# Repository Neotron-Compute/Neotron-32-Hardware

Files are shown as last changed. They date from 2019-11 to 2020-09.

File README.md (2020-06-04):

# Neotron 32

## A simple 32K ARM-powered home computer.

The Neotron 32 brings the classic 1980s home-computer design up-to-date. Our tech is based on the tried and true single board ARM computer model offering a hacker friendly platform for your retro project. It aims to bring the retro computing feel, with DOS and BASIC like environments and semi-modern interfaces, like SD cards and SVGA. And all the system software is Open Source and written in the Rust Programming Language, and all the hardware is Open Source too.

With an ARM Cortex-M4 based MCU the Neotron-32 gets you right back into the hardware. With only 32 KiB of RAM, the challenge is to squeeze the maximum out of the minimum amount of resources. We've got 48x36 text mode, 384x288 bitmap mode, 3-channel audio synthesiser, joystick support and FAT filesystem support ... but there's still room for you to squeeze some more out the system.

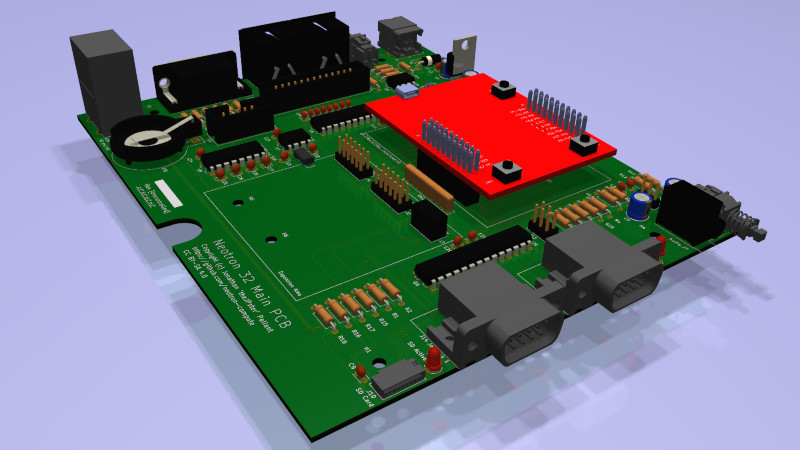
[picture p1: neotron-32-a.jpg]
Right Hand View


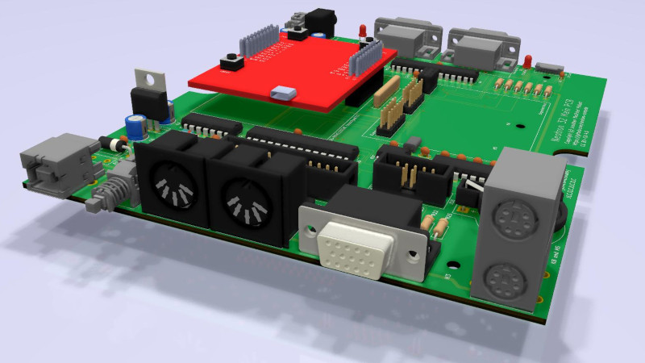
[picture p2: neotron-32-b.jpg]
Left Hand View


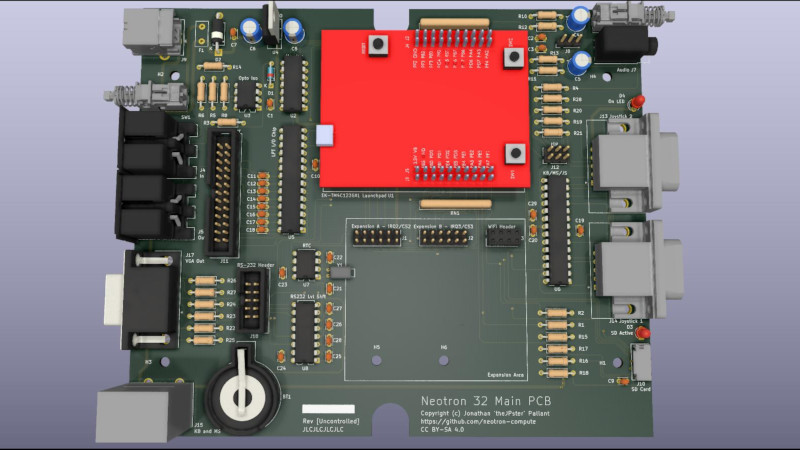
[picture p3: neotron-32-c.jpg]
Top View


## Hardware

  - **CPU:** Texas Instruments Tiva-C TM4C123
  - **Processor Core**: 80 MHz ARM Cortex-M4 (approximately 95% CPU taken drawing the screen, leaving a ~ 4 MHz ARM)
  - **RAM:** 32 KiB on-chip SRAM
  - **ROM:** 256 KiB on-chip Flash
  - **GPU:** No GPU - CPU generates 8 colour 400x300 video
  - **GPU RAM:** Shared with main SRAM
  - **Video Output:** VGA (fixed at 800x600 60 Hz)
  - **Storage:** Micro SD Card slot, supports FAT16/FAT32 and MS-DOS partition tables
  - **USB:** 1x USB 2.0 Full-speed OTG micro-AB port (internal - support TBD)
  - **Audio:** 3.5mm Line Out with Mono/Stereo jumper
  - **Keyboard/Mouse:** 2x PS/2 Ports (2x 6-pin mini-DIN)
  - **MIDI**: MIDI In and MIDI Out (2x 5-pin 180-degree DIN)
  - **Serial**: RS-232 on 10-pin 2.54mm header suitable for DE-9 plug on IDC ribbon
  - **Parallel**: 3.3v PC-style Parallel Port on 26-pin 2.54mm header suitable for DB-25 plug on IDC ribbon. Also functions as 3.3v GPIO with 12 outputs and 4 inputs.
  - **Joystick**: 2x 9-pin game ports (supports Atari-compatible two-button joysticks, or SEGA MegaDrive/Genesis controllers)
  - **Expansion**: 2x internal 2.54mm 2x6 headers carrying power, SPI, I2C and a dedicated IRQ line
  - **Wi-Fi**: 2x4 pin socket for ESP-01 Wi-Fi module
  - **RTC**: MCP7940 Real-time clock, with coin-cell battery backup
  - **Mechanical Form Factor:** Fits Hammond [1598C] case

[1598C]: ./datasheets/Hammond%201598C.pdf

## Parts Required

  - **PCBA**: Load the [Neotron-32 schematic](./neotron-32.sch) in Kicad, or see the [Neotron-32 Release Area] on Github for PDFs, Gerbers and a CSV bill-of-materials.
  - **Case**: Hammond [1598C], in your choice of colour. The case will include mounting screws, feet and two un-cut end panels.
  - **End panels**: Cut the panels supplied with the case according to [the drawing](./endpanels/endpanels.dxf). There is a PDF version in the [Neotron-32 Release Area].
  - **SD Card**: Any micro-SD or micro-SDHC card should work. Tested with Sandisk 8GB micro-SDHC cards, formatted with a single FAT32 partition.
  - **Monitor**: You will need monitor with 15-pin VGA input that can handle 800x600 resolution @ 60 Hz. Most higher resolution LCD panels will up-scale the image, but the quality of the scaling may not be ideal. A CRT will give a better image, but you may need to wind up the contrast and brightness to get a workable picture. An old 800x600 native resolution LCD would be ideal.
  - **Power Supply**: You need a standard mobile phone charger or other USB power source, and a standard USB A to B cable (like you would use for a USB printer).
  - **Ribbon cables**: The DB25 Parallel Port and DE9 RS-232 Serial port require a 2.54mm pin header to D-Sub ribbon cable. You can scavenge them from an old PC, or buy them new from Amazon, eBay or AliExpress for a few UK pounds.
  - **Keyboard and Mouse**: Any PS/2 Keyboard and PS/2 Mouse should work. In theory you could also use an RS-232 Serial Mouse but there's no driver support for that.
  - **Tiva-C Launchpad**: Contains the brains of the system. You want the EK-TM4C123GXL - *not* the EK-TM4C129 (which is much larger), or the older LM4F120 Launchpad (which is almost compatible, but audio won't work). You can buy these online at places like [Digikey](https://www.digikey.co.uk/products/en?keywords=296-35760-ND) or [Farnell](https://uk.farnell.com/texas-instruments/ek-tm4c123gxl/launchpad-tiva-c-evaluation-kit/dp/3126091).
  - **Joysticks**: Any Atari-compatible 9-pin digital joystick should work. You can connect up to two at once, for two player gaming. Sega MegaDrive/Genesis controllers should also work (although on the 6-button variant only the main A/B/C/Start buttons will work, not the extra three fire buttons).
  - **Audio**: The audio output is straight from the microcontroller and so is pretty weak. We recommend using amplified speakers, or an external headphone amplifier. Connecting headphones directly is untested and may pull too much current from the microcontroller.
  - **MIDI**: If you want to hook up a MIDI Synthesiser like a Roland MT-32, or a MIDI Keyboard, you just need standard 5-pin DIN MIDI cables. USB MIDI devices are not supported.
  - **USB**: The Tiva-C Launchpad has a USB micro-AB connector into which you can plug a Raspberry Pi Zero compatible micro-A to full-size A adaptor. There is no USB support in firmware yet, and the board can only supply a limited amount of current, so don't expect your mobile phone to charge.
  - **Switches**: You'll need a 250 mA On/Off switch you can fix to the case to power the unit on (or short the header with a jumper), plus a momentary switch to reset the system.

You can find a complete BOM (including the Tiva-C Launchpad and all the connectors, but excluding the PCB, case and Serial/Parallel ribbon cables), on [Octopart]. Gerbers and BOM are also available on [OpenHardware] and [Kitspace]. Don't forget, if you get the Hammond case, you'll need to drill out or mill the endplates yourself to take the connectors.

[Neotron-32 Release Area]: https://github.com/Neotron-Compute/Neotron-32-Hardware/releases
[Octopart]: https://octopart.com/bom-tool/tBdBR3vl
[OpenHardware]: https://www.openhardware.io/view/783/Neotron-32
[Kitspace]: https://kitspace.org/boards/github.com/neotron-compute/neotron-32-hardware/

## Git Setup

We recommend you have the following Git config set:

```console
$ git config --global filter.kicad_project.clean "sed -E 's/^update=.*$/update=Date/'"
$ git config --global filter.kicad_project.smudge cat
$ git config --global filter.kicad_sch.clean "sed -E 's/#(PWR|FLG)[0-9]+/#\1?/'"
$ git config --global filter.kicad_sch.smudge cat
```

See https://jnavila.github.io/plotkicadsch/ for details.

## Software

You will need to flash both the [Neotron 32 BIOS](https://github.com/neotron-compute/Neotron-32-BIOS) and the [Neotron OS](https://github.com/neotron-compute/Neotron-OS). The TM4C123 Launchpad has an on-board USB programming tool, which is supported by OpenOCD, so no extra hardware is required.

Once running the OS, you can load applications from the SD card. Applications can be written in C or in Rust, using the [Neotron SDK](https://github.com/neotron-compute/Neotron-SDK).

## Licence

This schematic and PCB design is Copyright (c) Jonathan 'theJPster' Pallant and other Neotron 32 contributors.



This work is licensed under a [Creative Commons Attribution-ShareAlike 4.0 International License](http://creativecommons.org/licenses/by-sa/4.0/).

## Contribution Agreement

Unless you explicitly state otherwise, any contribution intentionally submitted for inclusion in the work by you, as defined in the Apache-2.0 license, shall be licensed as above, without any additional terms or conditions.

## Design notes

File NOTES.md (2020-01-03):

# DE9 Sockets

The joystick sockets should be plastic, not metal.

TE 5747467, comes in -1 (flash), -2 (more gold), and -4 (lots of gold?). Quite pricey. Has different footprint to 'standard' DE9 - pins are set back from mounting pins. Will need custom footprint.

https://www.mouser.co.uk/ProductDetail/TE-Connectivity/5747467-1 - £5.22
https://www.mouser.co.uk/ProductDetail/TE-Connectivity/5747467-2 - £3.14
https://uk.rs-online.com/web/p/pcb-d-sub-connectors/7183433/ - £5.38
https://uk.farnell.com/amp-te-connectivity/5747467-1/hd-20-plug-9p-ra-590/dp/2976224?st=5747467 - £4.82, MOQ 10
https://www.digikey.co.uk/product-detail/en/te-connectivity-amp-connectors/5747467-2/A109156-ND/4030375 - £2.44

I got some of the 5747467 parts (the -1, -2, -4 etc indicate the quality of the gold plating). Sadly, they don't have any boardlocks, so the user will need to attach them to the PCB with M3 (or 4-40?) machine screws and nuts. Not ideal!

Are there any other black plastic DE9 male sockets? Try Harting, Kycon, Amphenol, etc.

A surplus store in Nebraska has some super cheap - 65 cents each!

http://www.surplussales.com/ComputerAccess/DBConn-1.html

# Dual PS/2 Header

Bought some from Alibaba. Found a PDF online from Kycon. I think I also found a second vendor and the diagrams matched to within 0.1mm.

Kycon KMDGX-6S/6S-S4N - http://www.kycon.com/Pub_Eng_Draw/KMDGX-6S-6S-S4N.pdf
Adam Tech MDJD-006-FS-RT - http://adam-tech.com/downloader.php?p=MDJD-006-FS-RT.pdf
Switchcraft DMD6FRA111 - http://datasheet.octopart.com/DMD6FRA111-Switchcraft-datasheet-11728953.pdf
TE 1734021-4 - http://sigma.octopart.com/14744532/technical_drawing/AMP-1734021-4.pdf

https://www.digikey.com/products/en/connectors-interconnects/circular-connectors/436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

I also bought the Kycon one from Mouser and it looks good (although black/black not purple/green).

# Case

I'm using a Hammond 1598C, with Parallel Port and Serial Port on ribbons.

I bought one NOS, and the screws were rusty. I bought a new one from Mouser in Beige and the finish on the parts where they meet in the middle wasn't great.

# BOM

Octopart https://octopart.com/bom-tool/nhQ4pql9

# TODO List

Need to do a front panel.
Maybe swap the DB25 and DE9 headers for boxed ones, so you can't plug them in the wrong way around?

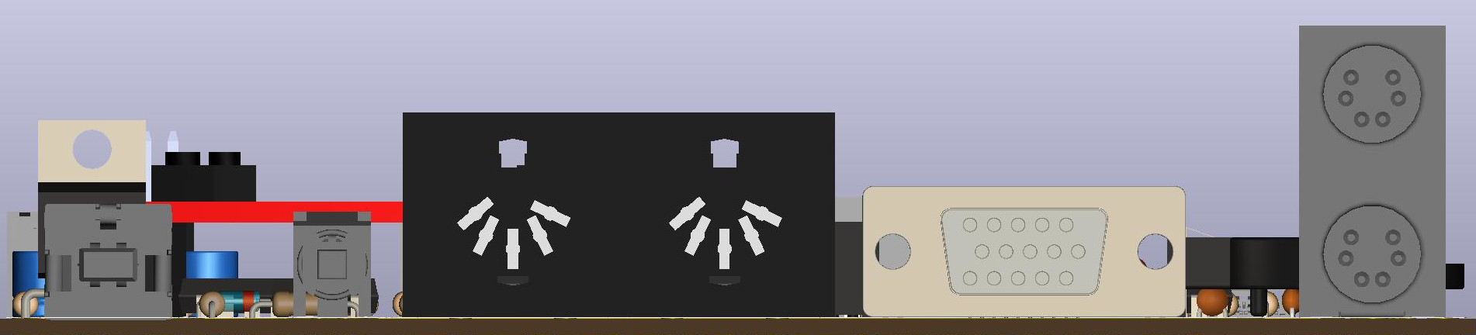
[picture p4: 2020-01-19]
neotron-32-end.jpg

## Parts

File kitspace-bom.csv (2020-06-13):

Reference | Quantity | Description | Datasheet | Manufacturer | mpn | digikey# | rs#
BT801 | 1 | Battery Holder | ~ | Keystone | 103 | 36-103-ND‎
BT801 | 1 | CR2023 Battery | ~ | Panasonic | CR2032 | P189-ND
C201 C402 C501 C601 C702 C701 C703 C803 C1003 C1004 C1002 C1001 C1005 | 13 | 100nF Disc Capacitor Through-Hole 2.50mm lead pitch | ~ | Vishay | K104K15X7RF5TL2 | BC1084CT-ND‎
C302 C301 | 2 | 33nF Disc Capacitor Through-Hole 2.50mm lead pitch | ~ | Vishay | K333K15X7RF5TL2 | ‎BC1081CT-ND‎
C303 C304 C401 | 3 | 10uF Radial Electrolytic Capacitor 2.50mm lead pitch | ~ | Vishay | MAL203858109E3 | ‎BC5157-ND‎
C403 | 1 | 47uF Radial Electrolytic Capacitor 2.50mm lead pitch | ~ | Vishay | MAL214250479E3 | 4596PHBK-ND‎
C602 C609 C603 C604 C605 C608 C607 C606 | 8 | 22nF Disc Capacitor Through-Hole 2.50mm lead pitch | ~ | Vishay | K223K15X7RF5TL2 | BC1080CT-ND‎
C801 C802 | 2 | 6pF Disc Capacitor Through-Hole 2.50mm lead pitch | ~ | TDK | FG18C0G1H060DNT06 | 445-173167-1-ND‎
D201 | 1 | 1N148 DO-35 Diode Through-Hole 7.62mm lead pitch | ~ | ON Semi | 1N4148TR | 1N4148VSCT-ND‎
D401 | 1 | 5V DO-15 TVS Diode Through-Hole 12.7mm lead pitch | https://www.littelfuse.com/~/media/electronics/datasheets/tvs_diodes/littelfuse_tvs_diode_sa_datasheet.pdf.pdf | Littelfuse | SA5.0A | SA5.0ALFCT-ND‎
D402 D501 | 2 | Red LED Through-Hole 3.0mm lead pitch | ~ | Würth Elektronik | 151031SS04000 | 732-5005-ND‎
F401 | 1 | PTC resettable fuse 72V 250mA | https://www.littelfuse.com/~/media/electronics/product_specifications/resettable_ptcs/littelfuse_ptc_rxef025_product_specification.pdf.pdf | Littelfuse Inc | RXEF025 | RXEF025HF-ND‎
J1001 | 1 | 10 pin (2x5) boxed 2.54mm header for IDC cable | ~ | On Shore Technology | 302-S101 | ED1543-ND‎
J101 J102 | 2 | 12 pin (2x6) 2.54mm header | ~ | Harwin | M20-9980646 | 952-2126-ND
J103 | 1 | 8 pin (2x4) 2.54mm socket | ~ | Adam Tech | RS2-08-G | 2057-RS2-08-G-ND‎
J202 J201 | 2 | 5 pin DIN 180 Socket | https://docs.rs-online.com/1ee9/0900766b81579be1.pdf | RS | 491-087 |  | 491-087
J301 | 1 | 3.5mm Audio Jack TRS | ~ | CUI | SJ1-3533NG | CP1-3533NG-ND‎
J302 | 1 | 3 pin (1x3) 2.54mm header | ~ | Harwin | M20-9770346 | 952-1777-ND
J401 | 1 | USB B Through-Hole Connector | http://www.on-shore.com/wp-content/uploads/USB-B1HSXX.pdf | On Shore Technology | USB-B1HSB6 | ED2983-ND‎
J501 | 1 | microSD Connector surface-mount |  | Molex | 47309-2651 | WM6700CT-ND‎
J601 | 1 | 26 pin (2x13) boxed 2.54mm header for IDC cable | ~ | On Shore Technology | 302-S261 | ‎ED10526-ND‎
J701 | 1 | 6 pin (2x3) 2.54mm header | ~ | Harwin | M20-9760346 | ‎952-1779-ND‎
J702 J703 | 2 | 9-pin DE-shell D-Sub, plastic, through-hole, male | https://www.te.com/commerce/DocumentDelivery/DDEController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 | TE | 5747467-2 | ‎A109156-ND‎
J704 | 1 | Stacked dual PS/2 (mini 6-pin DIN) connector | http://www.kycon.com/Pub_Eng_Draw/KMDGX-6S-6S-S4N.pdf | Kycon | KMDGX-6S-6S-S4N. | 2092-KMDGX-6S/6S-S4N-ND‎
J901 | 1 | 15-pin DE-shell D-Sub, through-hole, female | https://www.amphenol-icc.com/media/wysiwyg/files/drawing/c-cd-0012.pdf | Amphenol | ICD15S13E4GV00LF | 609-5180-ND‎
R102 R101 R701 R702 R703 | 5 | 1k through-hole resistor, 10.16mm lead pitch | ~ | Stackpole Electronics Inc | CF14JT1K00 | CF14JT1K00CT-ND
R202 R203 R201 | 3 | 220R through-hole resistor, 10.16mm lead pitch | ~ | Stackpole Electronics Inc | CF14JT220R | CF14JT220RCT-ND
R204 | 1 | 10k through-hole resistor, 10.16mm lead pitch | ~ | Stackpole Electronics Inc | CF14JT10K0 | CF14JT10K0CT-ND
R205 | 1 | 470R through-hole resistor, 10.16mm lead pitch | ~ | Stackpole Electronics Inc | CF14JT470R | CF14JT470RCT-ND
R302 R301 | 2 | 270R through-hole resistor, 10.16mm lead pitch | ~ | Stackpole Electronics Inc | CF14JT270R | CF14JT270RCT-ND
R303 R304 | 2 | 150R through-hole resistor, 10.16mm lead pitch | ~ | Stackpole Electronics Inc | CF14JT150R | CF14JT150RCT-ND
R402 R403 R503 R906 R905 R901 R902 R903 | 8 | 330R through-hole resistor, 10.16mm lead pitch | ~ | Stackpole Electronics Inc | CF14JT330R | CF14JT330RCT-ND
R502 R501 | 2 | 47k through-hole resistor, 10.16mm lead pitch | ~ | Stackpole Electronics Inc | CF14JT47K0 | CF14JT47K0CT-ND
RN101 RN102 | 2 | SIP9 47k Resistor Array | https://www.bourns.com/docs/Product-Datasheets/4600x.pdf | Bourns | 4609X-101-473LF | 4609X-101-473LF-ND‎
SW401 | 1 | Push Switch DPDT on/off | ~ | C&K | PHB2UEETS1A | CKN12287-ND‎
SW402 | 1 | Push Switch DPDT on/momentary | ~ | C&K | PHB2UOATS1A | CKN12288-ND‎
U1001 | 1 | 3.3v RS-232 level shifter (4 channel) | https://www.renesas.com/en-us/www/doc/datasheet/hin232-36-37-38-39-40-41.pdf | Renesas | ICL3232CPZ | ICL3232CPZ-ND‎
U1001 | 1 | 16 pin DIP socket |  | On Shore Technology | ED16DT | ‎ED3046-5-ND‎
U101 | 1 | Texas Instruments TM4C123GXL Launchpad | ~ | Texas Instruments | EK-TM4C123GXL | 296-35760-ND‎
U101 | 2 | 20 pin (2x10) 2.54mm header | ~ | Harwin | M20-9981046 | 952-2130-ND‎
U201 | 1 | 74LS14 Hex Inverter | http://www.ti.com/lit/gpn/sn74LS14 | Texas Instruments | SN74LS14N | 296-1643-5-ND‎
U201 | 1 | 14 pin DIP Socket |  | On Shore Technology | ED14DT | ‎ED3045-5-ND‎
U202 | 1 | 6N138 Opto-isolator | https://media.digikey.com/pdf/Data%20Sheets/Lite-On%20PDFs/6N138-39%20Series.pdf | Lite-On Inc. | 6N138 | ‎6N138IS-ND‎
U202 | 1 | 8 pin DIP socket |  | On Shore Technology | ED08DT | ED3044-5-ND‎
U401 | 1 | 3.3V LDO | http://ww1.microchip.com/downloads/en/DeviceDoc/21373C.pdf | Microchip | TC1262-3.3VAB | TC1262-3.3VAB-ND‎
U601 | 1 | MCP23S17 SPI GPIO Expander | http://ww1.microchip.com/downloads/en/DeviceDoc/20001952C.pdf | Microchip | MCP23S17-E/SP | MCP23S17-E/SP-ND‎
U601 | 1 | 28 pin DIP socket |  | On Shore Technology | ED281DT | ‎ED3050-5-ND‎
U701 | 1 | Atmega328 | http://ww1.microchip.com/downloads/en/DeviceDoc/ATmega328_P%20AVR%20MCU%20with%20picoPower%20Technology%20Data%20Sheet%2040001984A.pdf | Microchip | ATmega328-PU | ATMEGA328-PU-ND‎
U701 | 1 | 28 pin DIP socket |  | On Shore Technology | ED281DT | ED3050-5-ND‎
U801 | 1 | MCP7940 Real-Time Clock | http://ww1.microchip.com/downloads/en/DeviceDoc/20005010F.pdf | Microchip | MCP7940N-I/P | MCP7940N-I/P-ND‎
U801 | 1 | 8 pin DIP socket |  | On Shore Technology | ED08DT | ED3044-5-ND‎
Y801 | 1 | 32.768 kHz RTC Crystal through-hole | http://cfd.citizen.co.jp/english/prod-tech/product/pdf/datasheet_TF/CFS-206_CFS-145_E.pdf | Citizen | CFS-20632768DZBB | 300-8301-ND‎

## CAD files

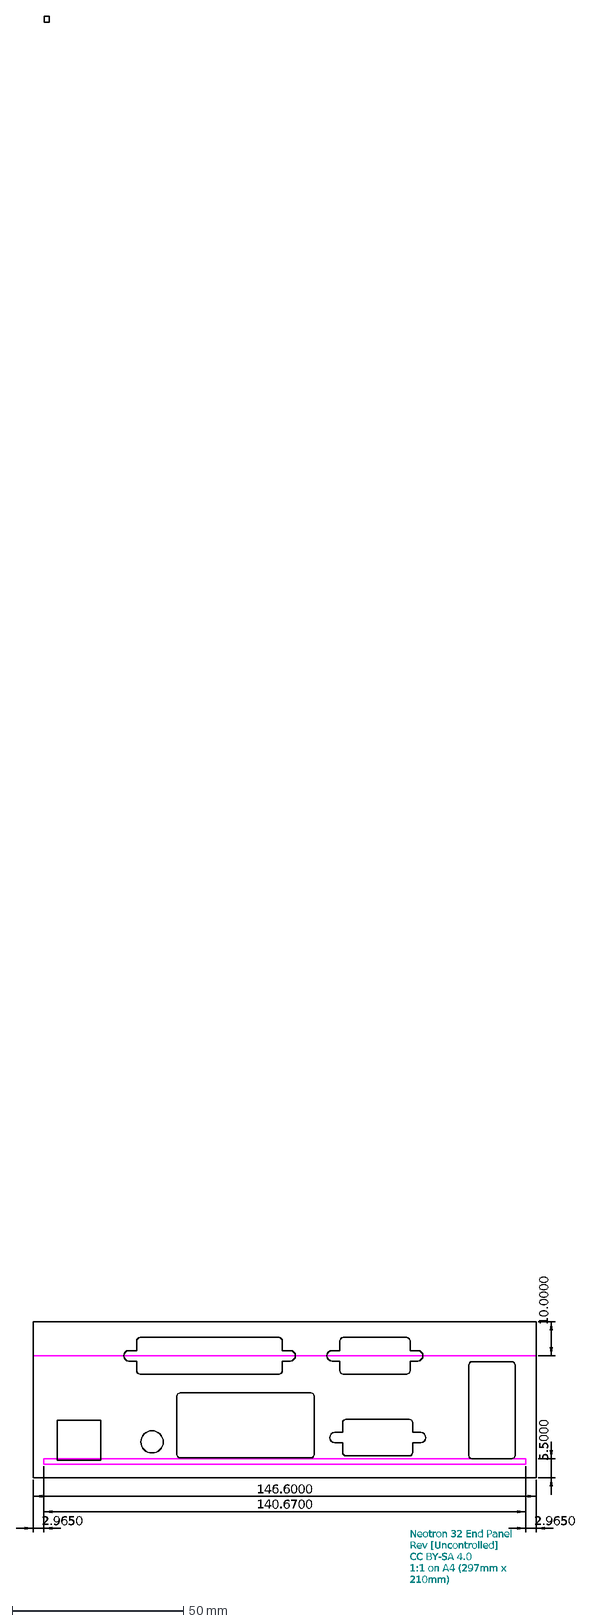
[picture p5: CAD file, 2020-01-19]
endpanels/endpanels.dxf
10.0000
5.5000
140.6700
Neotron 32 End Panel Rev [Uncontrolled] CC BY-SA 4.0 1:1 on A4 (297mm x 210mm)
146.6000
2.9650

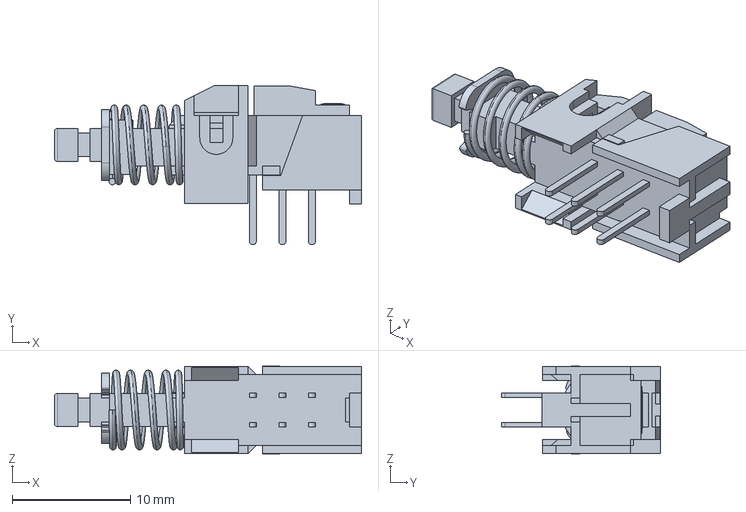
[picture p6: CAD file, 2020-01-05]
models/PHB2UOATS1ANS.stp
26.0 x 13.5 x 7.42 mm

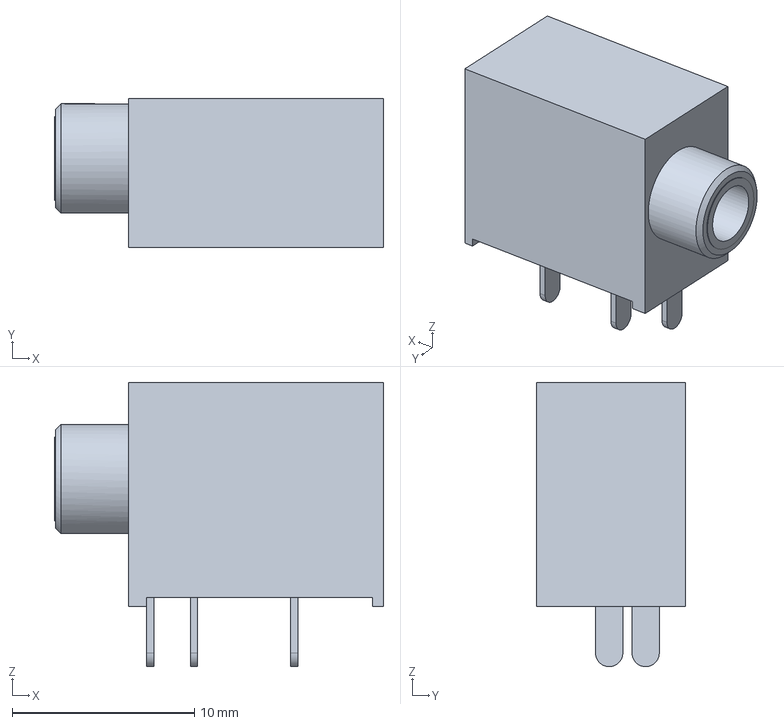
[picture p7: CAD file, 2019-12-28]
models/129c20533c2cd7dda318afc41ae7ab4f8828891e.step
18.1 x 8.20 x 15.6 mm

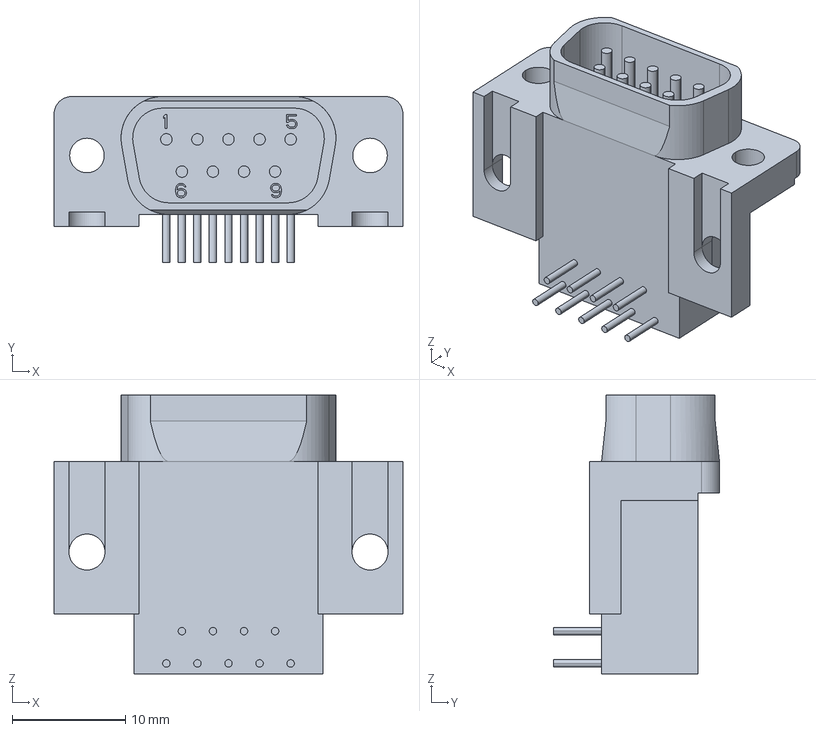
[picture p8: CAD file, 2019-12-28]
models/c-5747467-2-b-3d.stp
30.8 x 14.7 x 24.6 mm

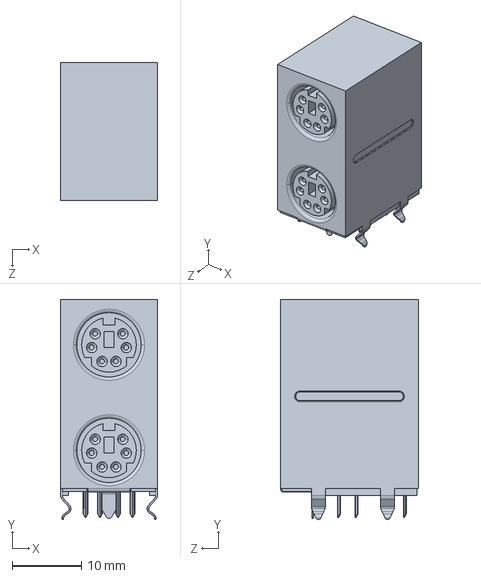
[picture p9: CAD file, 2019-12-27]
models/KMDGX-6S-6S-S4N_rB8.STEP
14.0 x 31.8 x 20.0 mm

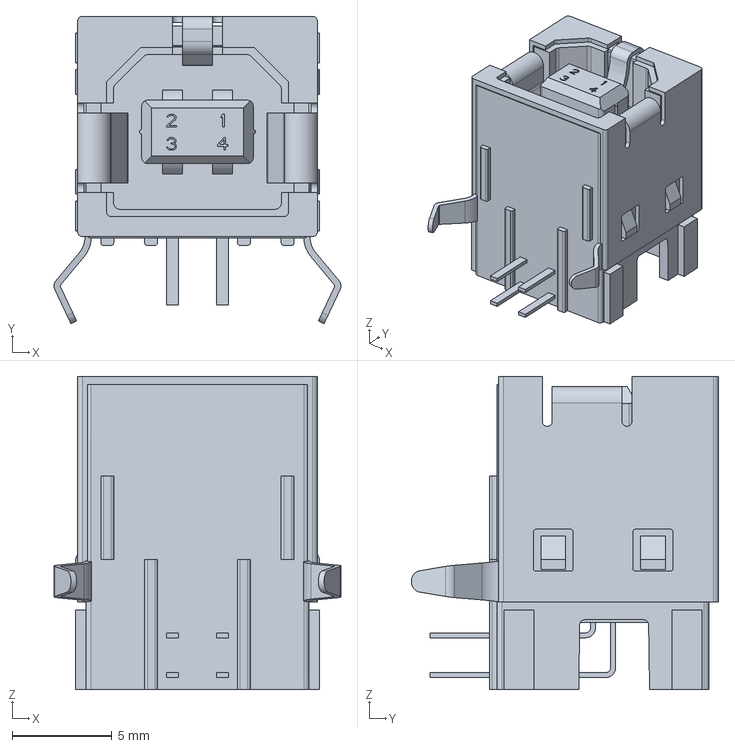
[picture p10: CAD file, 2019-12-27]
models/c-292304-1-b-3d.stp
14.4 x 15.4 x 15.7 mm

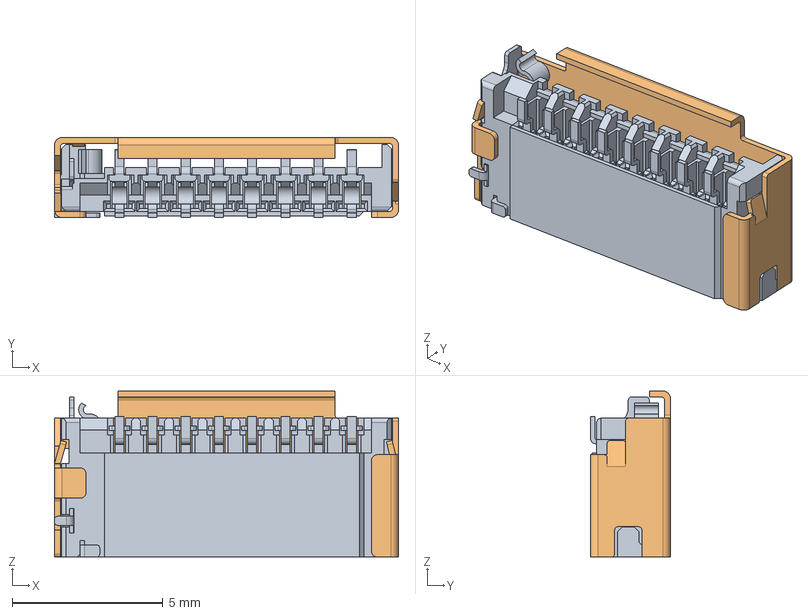
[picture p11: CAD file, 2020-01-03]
models/473092651.stp
11.4 x 2.65 x 5.50 mm

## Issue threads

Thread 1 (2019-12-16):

1.0 Schematic

thejpster, 2019-12-16:

thejpster, 2019-12-16:
Schematic completed. Needs review and footprints allocating.

thejpster, 2019-12-20:
v0.7.0 is up for review.

IGBC, 2019-12-21:
Yes looks good to me

thejpster, 2019-12-21:
For completeness I issued 0.8.0 today. On the schematic side it just swaps two PS/2 sockets for one double socket.

thejpster, 2019-12-21:
I'm now allocating part numbers so we can place an order on Octopart using the metadata in the schematic.

thejpster, 2020-01-19:
Commit and be damned. v1.2.0 out for manufacture.

Closed 2020-01-19.

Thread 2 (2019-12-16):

1.0 PCB Layout

thejpster, 2019-12-16:

thejpster, 2019-12-20:
v0.7.0 for review. I'm aware the PS/2 footprint is wrong.

thejpster, 2019-12-21:
v0.8.0 released. PS/2 footprints corrected. No known issues remaining.

thejpster, 2019-12-28:
Up to v0.9.1. Now waiting on #13.

thejpster, 2020-01-19:
Commit and be damned. v1.2.0 out for manufacture.

Closed 2020-01-19.

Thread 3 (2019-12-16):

1.0 Boards

thejpster, 2019-12-16:
PCBway have expressed an interest in doing these.

thejpster, 2019-12-21:
JLCPCB work out way cheaper than PCBway. They did an OK job on Monotron but the silk screen was a bit sketchy in places.

thejpster, 2020-01-19:
Commit and be damned. v1.2.0 out for manufacture.

thejpster, 2020-01-30:
Still waiting on boards.

thejpster, 2020-03-13:
Boards arrived 10 March.

Closed 2020-03-13.

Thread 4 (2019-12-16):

1.0 PCBA

thejpster, 2019-12-16:

thejpster, 2020-03-13:
Loading first board in progress.

Made error loading LDO by using random LDO I had in the drawer rather than the specific part. Pinout didn't match and went dead short. Luckily the PTC cut out, but I thought the PTC was faulty so I bypassed it.

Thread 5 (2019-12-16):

1.0 PCBA Components

thejpster, 2019-12-16:
Prefer Digikey

thejpster, 2019-12-21:
I'm adding Manufacturers and MPNs to all the parts. Octopart can then build us a BOM.

Note: Some parts are needed which are not on the schematic. We need a higher level assembly drawing which pulls in the PCBA,plus:

thejpster, 2019-12-28:
BOM now on Octopart, and all parts on Schematic updated.

Closed 2019-12-28.

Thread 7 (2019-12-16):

Render drawings in CI

thejpster, 2019-12-16:
Kicad Automation task hangs waiting for window to open.

eeshow renders schematic but all components are missing. Have contacted author.

IGBC, 2019-12-16:
Maybe automating DRC and ERC in CI is also worth doing?

thejpster, 2019-12-16:
Agreed. Title changed.

The kicad automation can do DRC, Gerber's, ERC and pdf plots. The eeshow tool is an independent renderer of eeschema drawings, so won't do ERC or DRC or Gerber's, but it doesn't involve running Kicad in a headless X server and doing screen scraping.

thejpster, 2019-12-21:
Looks like it might be a Docker/X issue. If I run Docker with the --user argument on my machine I get the same issue GitHub Actions shows.

I at least have a release script now so I can rattle off ERC, DRC and all the plots with a one liner.

thejpster, 2021-06-18:
See Neotron Pico for an example of how to do this.

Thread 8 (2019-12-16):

Add DCP detect circuit

thejpster, 2019-12-16:
2x2 jumpers. || wires LDO enable through D+ and D-, thus checking for a DCP. = (or _) would bypass that check.

thejpster, 2019-12-21:
I note Raspberry Pi do not check for D+ and D- tied together (i.e. being powered from a DCP). They seem to just rely on the host port doing the right thing if too much current is pulled. And actually, Monotron is under 100 mA anyway (I measured it at 77 mA with the SD card not initialised).

I'm electing to not do this for 1.0.

Closed 2019-12-21.

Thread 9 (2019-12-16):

faulty schematic for audio section in Release 0.6

IGBC, 2019-12-16:
Audio connectors are wired incorrectly in the 0.6 schematic.

Band-pass audio filter also looks suspect, and should be reviewed.

thejpster, 2019-12-17:
It's a straight copy of the Monotron schematic, which as far as I know, works fine. Any differences from that would be a bug. The low pass filter is the same as the Raspberry Pi Zero.

thejpster, 2019-12-28:
Are you happy with the audio circuit as-is or does it need changing?

Closed 2020-01-19.

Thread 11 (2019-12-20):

Fix PS/2 footprint

thejpster, 2019-12-20:
I need to draw a footprint for the PS/2 double-stack header.

IGBC, 2019-12-20:
Is this really a bug?

thejpster, 2019-12-21:
Replaced with correct part.

Closed 2019-12-21.

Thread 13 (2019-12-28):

Power and reset switch

thejpster, 2019-12-28:
We should fit PCB mount through-hole switches for power and reset.

* Reset is an off-mom and only takes a small amount of current (100mA should be OK).
* Power is an on-off (or on-on) and needs to handle at least 500 mA. Our expected maximum current is 100 mA, and our PTC is 250 mA, so this gives us some margin.

The power switch will go next to the USB connector, moving the MIDI ports down. Ideally we'd get one that fitted inbetween the end panel and the mounting screw.

The reset switch would either go at the back or at the front, depending on what fits.

FYI, I'm saving the front-left corner for a future two port USB A connector stack.

thejpster, 2019-12-29:
Have ordered a couple of PCB mount right angle switches (like the C&K [PHB2UEETS1A](https://www.ckswitches.com/products/pushbutton/PHB/)) to test. I'll then decide whether I want them on the PCB, or on flying leads.

thejpster, 2020-01-19:
PCB mount seems fine.

Closed 2020-01-19.

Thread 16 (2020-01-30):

Button doesn't fit through rear endpanel

thejpster, 2020-01-30:
The power switch is too close to the edge of the PCB. This leaves the sprung section poking through the end panel (and the hole is currently too small for it to fit).

Solutions:

1. Widen the hole, leaving a ugly power switch sticking out about 25mm.
2. Move the switch back so only the endcap pokes through the hole.

We will need to make the same change to the reset switch.

thejpster, 2020-06-03:
Moved switches back in #25

Closed 2020-06-03.

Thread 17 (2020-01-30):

VGA amplifier

thejpster, 2020-01-30:
The TM4C can't really deliver enough current to drive 0.7V into 75 ohms. It can just about manage 0.6V into 75 ohms, but this is a little dim and pushing the GPIO outputs very hard.

We should add a transistor buffer, an 74-series buffer, or a proper analog VGA amplifier.

The SN74LVC244A might work, as a digital buffer. You'd put a potential divider on the output to get the 1.4V you need.

The [AD8044ANZ](https://uk.farnell.com/analog-devices/ad8044anz/op-amp-vf-r-r-quad-lp-14dip/dp/2074887) three channel video amplifier would be perfect, but it's £8.91.

The [MAX4395](https://uk.farnell.com/maxim-integrated-products/max4395eud/op-amp-85mhz-500v-us-tssop-14/dp/2510890) is much cheaper at £1.83, but it's surface mount.

thejpster, 2020-05-07:
The THS7314 is what all the Retro RGB adaptors do. As SCART is basically like VGA (but half the vertical resolution), it should do the trick? Only 70p a unit, but comes as a SOIC.

https://www.retrorgb.com/thsamps.html

https://www.digikey.co.uk/product-detail/en/texas-instruments/THS7316DR/296-26684-1-ND/2255104

thejpster, 2020-06-05:
The 3PEAK TPF133A-SR is a 36 MHz 3-channel video reconstruction filter and 75 ohm line driver. It costs $0.16 from LCSC. 36 MHz video bandwidth is OK for up to a 72 MHz pixel clock.

thejpster, 2021-06-18:
Suggest we copy the design from the Neotron Pico.

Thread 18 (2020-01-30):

SMT variant

thejpster, 2020-01-30:
It might be interesting to produce a surface-mount variant of the board. People could then practice their SMT soldering, or get a fab-house to load the boards on a Juki. 0805 would be a reasonable comprise on hand-solderability and board space. You could get a SMT LDO, AtMega, MCP23S17, MCP7940N, MAX3232 along with all the decoupling caps and resistors. That would just leave the headers and connectors to be hand soldered.

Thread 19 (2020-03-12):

Hole near SD card in wrong place

thejpster, 2020-03-12:
Needs to budge back a few mm. Must have moved accidentally.

thejpster, 2020-06-03:
Fixed in #25

Closed 2020-06-03.

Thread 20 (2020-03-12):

Launchpad headers too tight

thejpster, 2020-03-12:
The expansion headers are fine but the Launchpad headers are a bit tight. Widen the holes a bit.

Closed 2020-06-04.

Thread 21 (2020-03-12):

LDO holes too small

thejpster, 2020-03-12:
The LDO legs have little kinks in them. The holes are too small, so you can't get the LDO flush to the board. Maybe that's OK?

jonathanpallant, 2020-03-13:
Maybe we should leave space so the LDO can lay down flat on the PCB. Might be a bit more robust for transport/shipping.

thejpster, 2020-03-13:
Or we could make space to lay the LDO down flat. You'd have to bend the leads, or get one with bent leads.

Closed 2020-06-04.

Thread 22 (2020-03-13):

SD card is a pig to solder

thejpster, 2020-03-13:
It's just about doable, but it's not easy at all. A nice through-hole part, or something with at least 2mm pitch, would be much better.

thejpster, 2020-03-13:
Maybe something like https://www.mouser.co.uk/ProductDetail/Amphenol-Commercial-Products/GSD090012SEU?

thejpster, 2020-06-03:
I bought a full-size SD card holder, and you cannot get it and the two DE9 connectors inbetween the mounting holes. It also doesn't fit outside the mounting holes.

We either:
1) Stick with microSD
2) Move to full-size SD but make the card internal (i.e. not externally accessible)
3) Change the case

thejpster, 2020-06-09:
Option (4) occurred to me today.

4. Ship a second small PCB which takes a full-size SD card and sits on two 1x6 headers. These headers straddle the mounting screw, allowing the SD card to sit _above_ the mounting screw.

thejpster, 2021-06-18:
Even better idea, just use the micro SD adaptor from PJRC!

https://www.pjrc.com/store/sd_adaptor.html

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

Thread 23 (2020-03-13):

Order v1.3.0 boards

thejpster, 2020-03-13:
1.2.1 boards have enough issues that we need to spin another batch of five.

thejpster, 2020-06-03:
Blocked on #21

thejpster, 2020-06-03:
Blocked on #20

thejpster, 2020-06-04:
Need to complete bring-up on existing boards.

thejpster, 2020-06-04:
Blocked on #6

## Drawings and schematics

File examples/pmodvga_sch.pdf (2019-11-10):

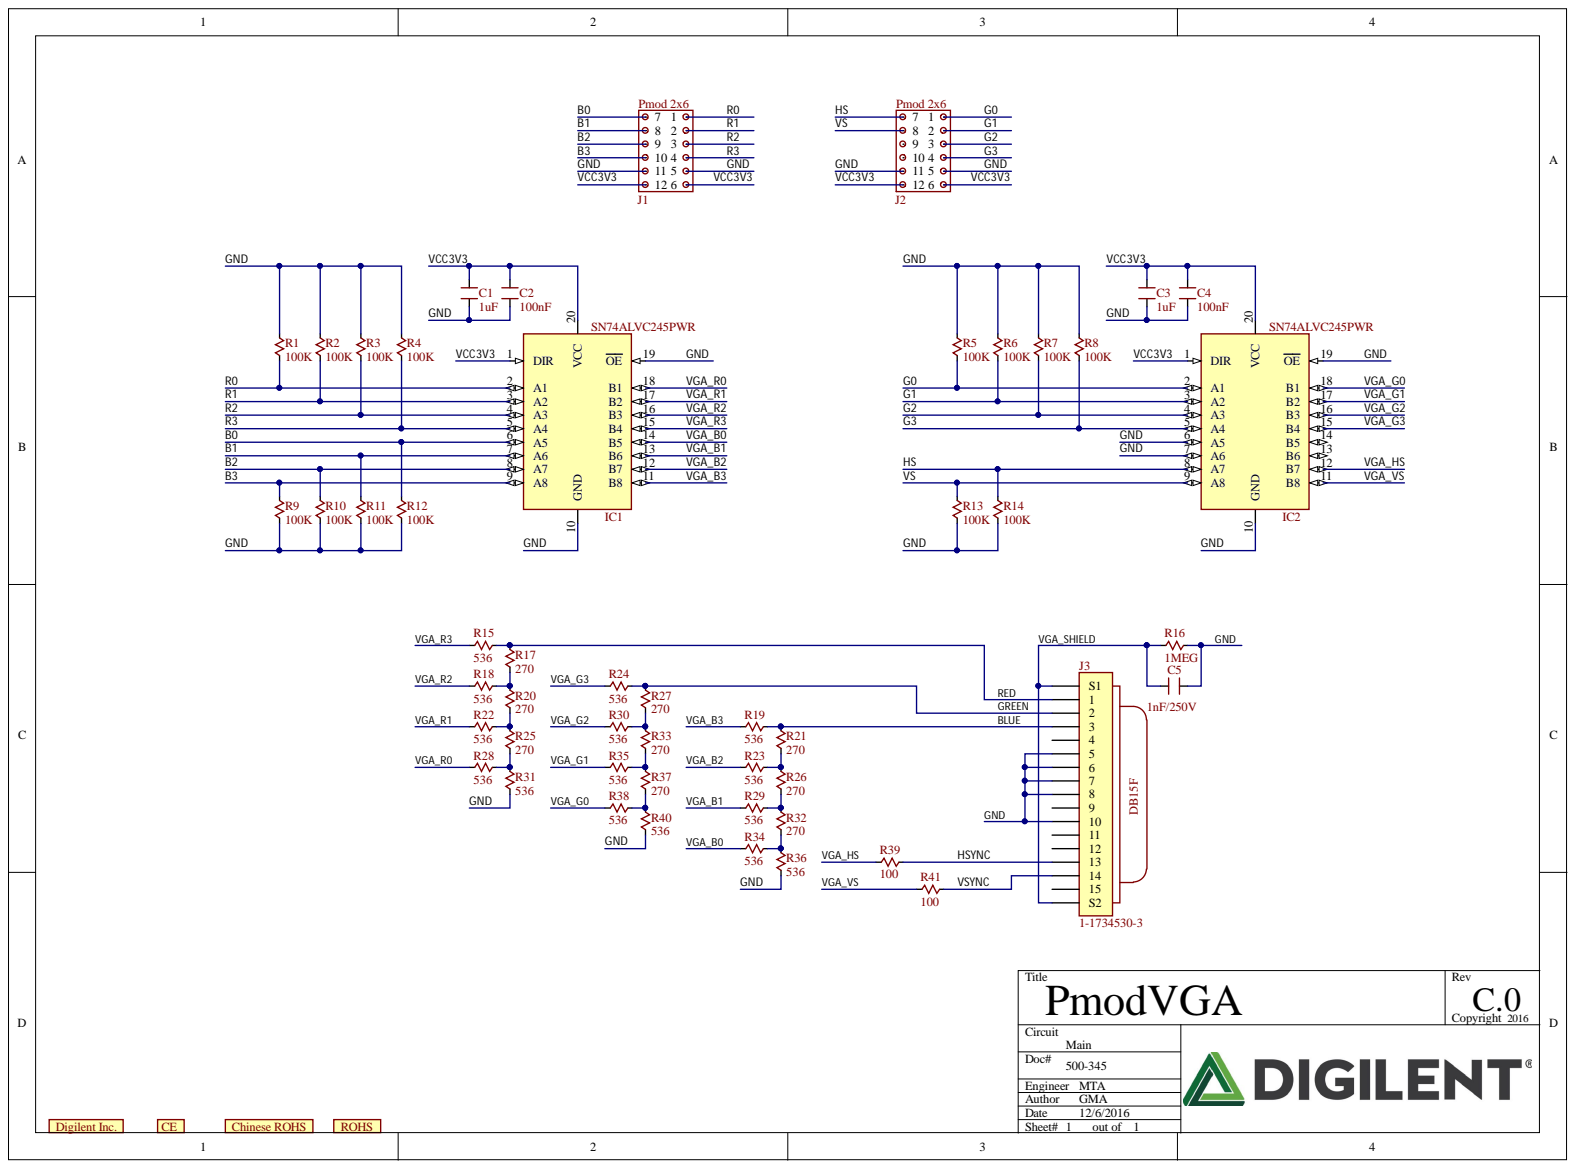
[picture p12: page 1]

RED R27
GREEN 270

BLUE

Title PmodVGA | Rev C.0 Copyright 2016

Circuit Main

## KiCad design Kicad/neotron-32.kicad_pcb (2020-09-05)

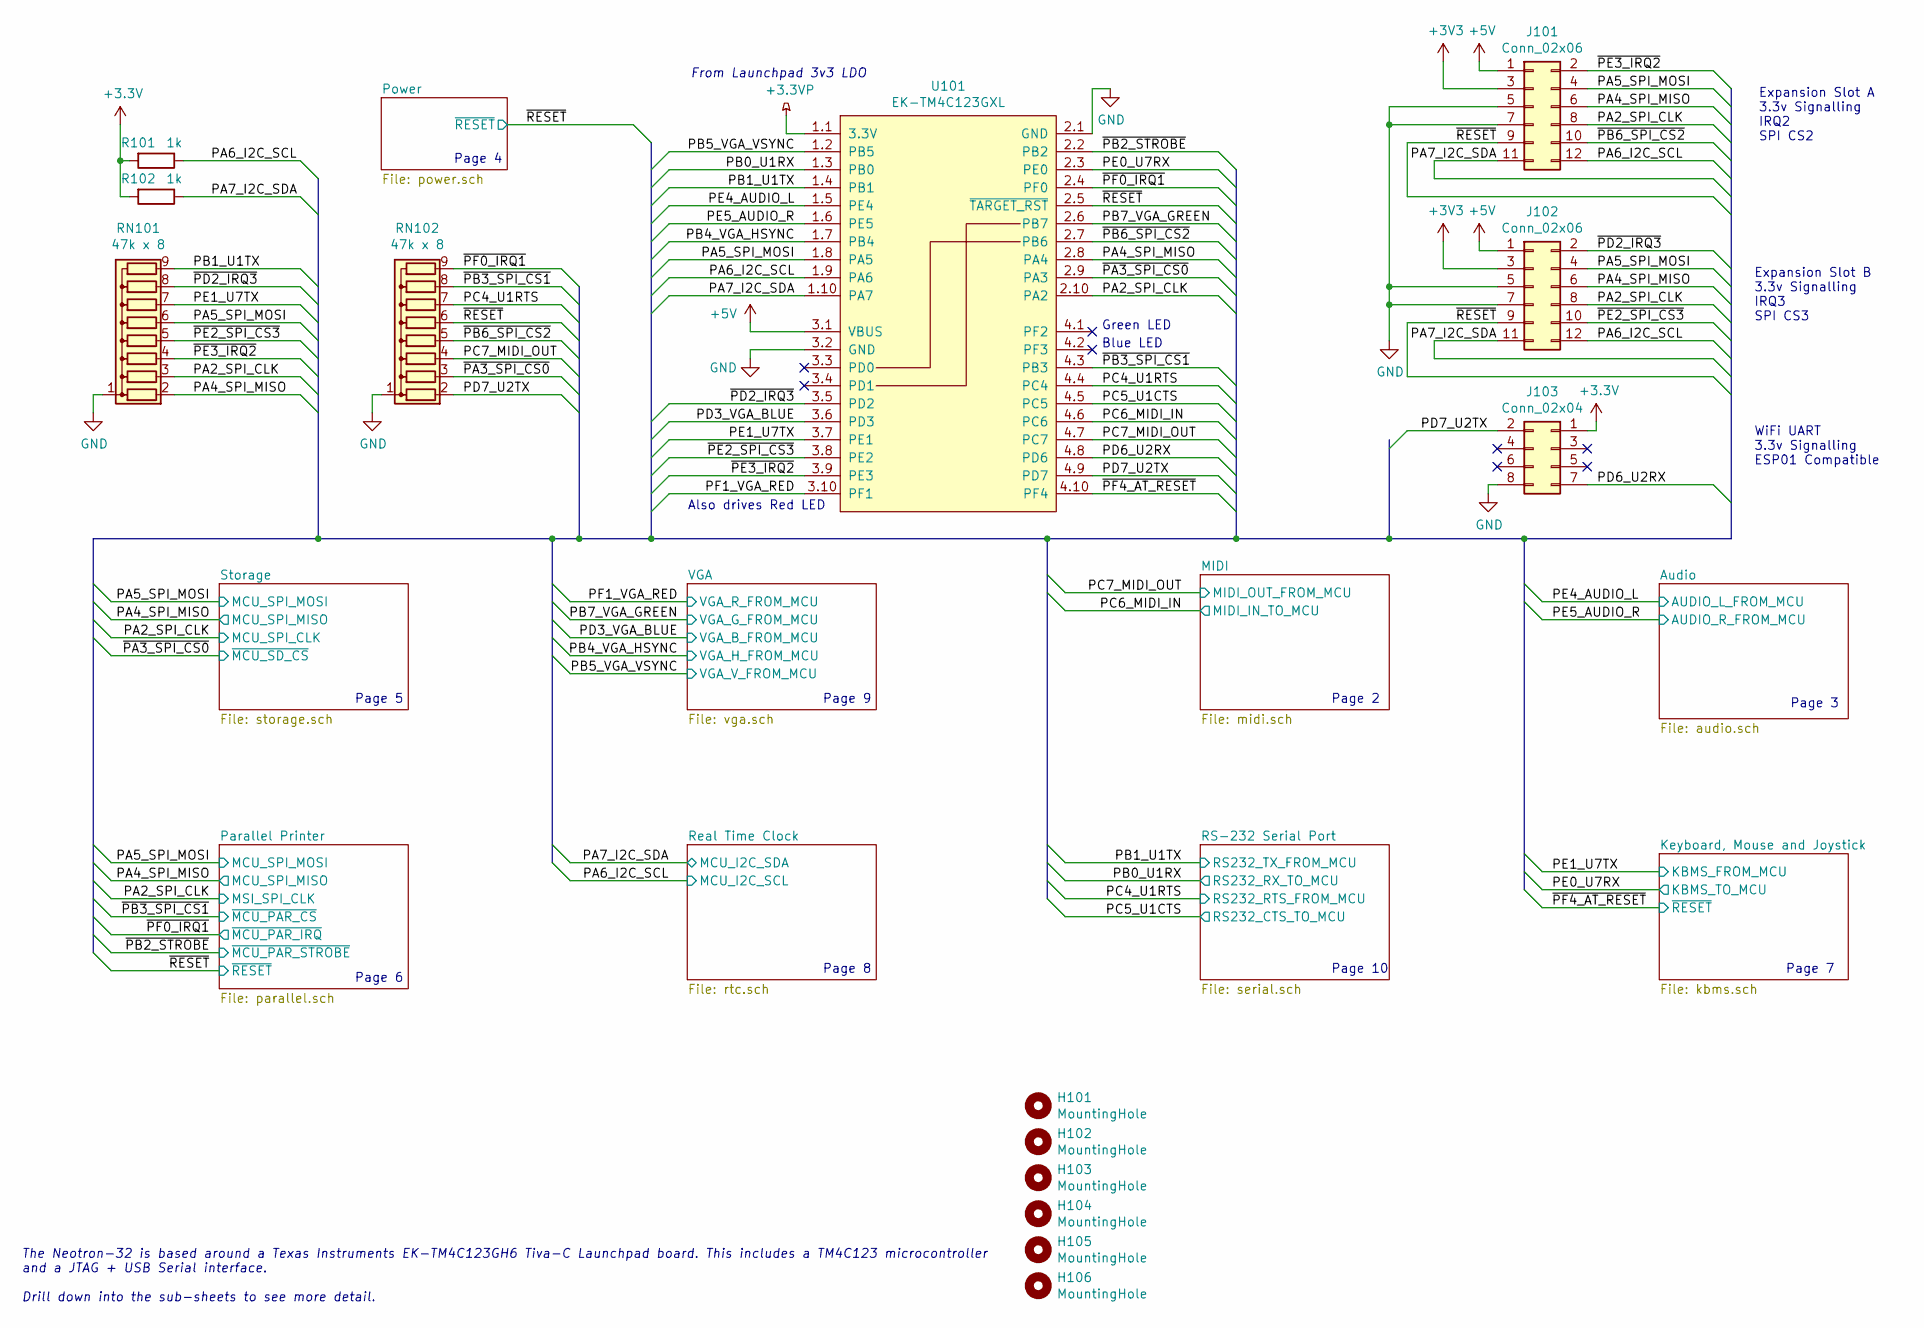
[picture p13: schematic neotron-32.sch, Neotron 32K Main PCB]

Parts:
H101, H102, H103, H104, H105, H106: MountingHole; MountingHole_3.5mm_Pad_Via
J101, J102: Conn_02x06; PinHeader_2x06_P2.54mm_Vertical; mpn M20-9760346
J103: Conn_02x04; PinSocket_2x04_P2.54mm_Vertical; mpn RS2-08-G
R101, R102: 1k; R_Axial_DIN0207_L6.3mm_D2.5mm_P10.16mm_Horizontal; mpn CF14JT1K00; digikey# CF14JT1K00CT-ND
RN101, RN102: 47k x 8; R_Array_SIP9; mpn 4609X-101-473LF
U101: EK-TM4C123GXL; Launchpad_4x10; mpn EK-TM4C123GXL;M20-9981046;M20-9981046; digikey# 296-35760-ND

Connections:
+3.3VP: U101.1.1 (3.3V)
+5V: J101.1, J102.1, U101.3.1 (VBUS); also elsewhere on the board
/PA2_SPI_CLK: J101.8, J102.8, RN101.3 (R2), U101.2.10 (PA2); also elsewhere on the board
/PA4_SPI_MISO: J101.6, J102.6, RN101.2 (R1), U101.2.8 (PA4); also elsewhere on the board
/PA5_SPI_MOSI: J101.4, J102.4, RN101.6 (R5), U101.1.8 (PA5); also elsewhere on the board
/PA6_I2C_SCL: J101.12, J102.12, R101.1, U101.1.9 (PA6); also elsewhere on the board
/PA7_I2C_SDA: J101.11, J102.11, R102.1, U101.1.10 (PA7); also elsewhere on the board
/PB0_U1RX: U101.1.3 (PB0); also elsewhere on the board
/PB1_U1TX: RN101.9 (R8), U101.1.4 (PB1); also elsewhere on the board
/PB4_VGA_HSYNC: U101.1.7 (PB4); also elsewhere on the board
/PB5_VGA_VSYNC: U101.1.2 (PB5); also elsewhere on the board
/PB7_VGA_GREEN: U101.2.6 (PB7); also elsewhere on the board
/PC4_U1RTS: RN102.7 (R6), U101.4.4 (PC4); also elsewhere on the board
/PC5_U1CTS: U101.4.5 (PC5); also elsewhere on the board
/PC6_MIDI_IN: U101.4.6 (PC6); also elsewhere on the board
/PC7_MIDI_OUT: RN102.4 (R3), U101.4.7 (PC7); also elsewhere on the board
/PD3_VGA_BLUE: U101.3.6 (PD3); also elsewhere on the board
/PD6_U2RX: J103.7, U101.4.8 (PD6)
/PD7_U2TX: J103.2, RN102.2 (R1), U101.4.9 (PD7)
/PE0_U7RX: U101.2.3 (PE0); also elsewhere on the board
/PE1_U7TX: RN101.7 (R6), U101.3.7 (PE1); also elsewhere on the board
/PE4_AUDIO_L: U101.1.5 (PE4); also elsewhere on the board
/PE5_AUDIO_R: U101.1.6 (PE5); also elsewhere on the board
/PF1_VGA_RED: U101.3.10 (PF1); also elsewhere on the board
/~PA3_SPI_CS0: RN102.3 (R2), U101.2.9 (PA3); also elsewhere on the board
/~PB2_STROBE: U101.2.2 (PB2); also elsewhere on the board
/~PB3_SPI_CS1: RN102.8 (R7), U101.4.3 (PB3~); also elsewhere on the board
/~PB6_SPI_CS2: J101.10, RN102.5 (R4), U101.2.7 (PB6)
/~PD2_IRQ3: J102.2, RN101.8 (R7), U101.3.5 (PD2)
/~PE2_SPI_CS3: J102.10, RN101.5 (R4), U101.3.8 (PE2)
/~PE3_IRQ2: J101.2, RN101.4 (R3), U101.3.9 (PE3)
/~PF0_IRQ1: RN102.9 (R8), U101.2.4 (PF0); also elsewhere on the board
/~PF4_AT_RESET: U101.4.10 (PF4); also elsewhere on the board
/~RESET: J101.9, J102.9, RN102.6 (R5), U101.2.5 (~TARGET_RST); also elsewhere on the board
GND: J101.5, J101.7, J102.5, J102.7, J103.8, RN101.1 (common), RN102.1 (common), U101.2.1 (GND), U101.3.2 (GND); also elsewhere on the board

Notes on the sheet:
Green LED
Blue LED
From Launchpad 3v3 LDO
Expansion Slot A 3.3v Signalling IRQ2 SPI CS2
WiFi UART 3.3v Signalling ESP01 Compatible
The Neotron-32 is based around a Texas Instruments EK-TM4C123GH6 Tiva-C Launchpad board. This includes a TM4C123 microcontroller and a JTAG + USB Serial interface. Drill down into the sub-sheets to see more detail.
Page 4
Page 5
Page 6
Page 8
Page 9
Page 2
Page 10
Page 3
Page 7
Expansion Slot B 3.3v Signalling IRQ3 SPI CS3
Also drives Red LED

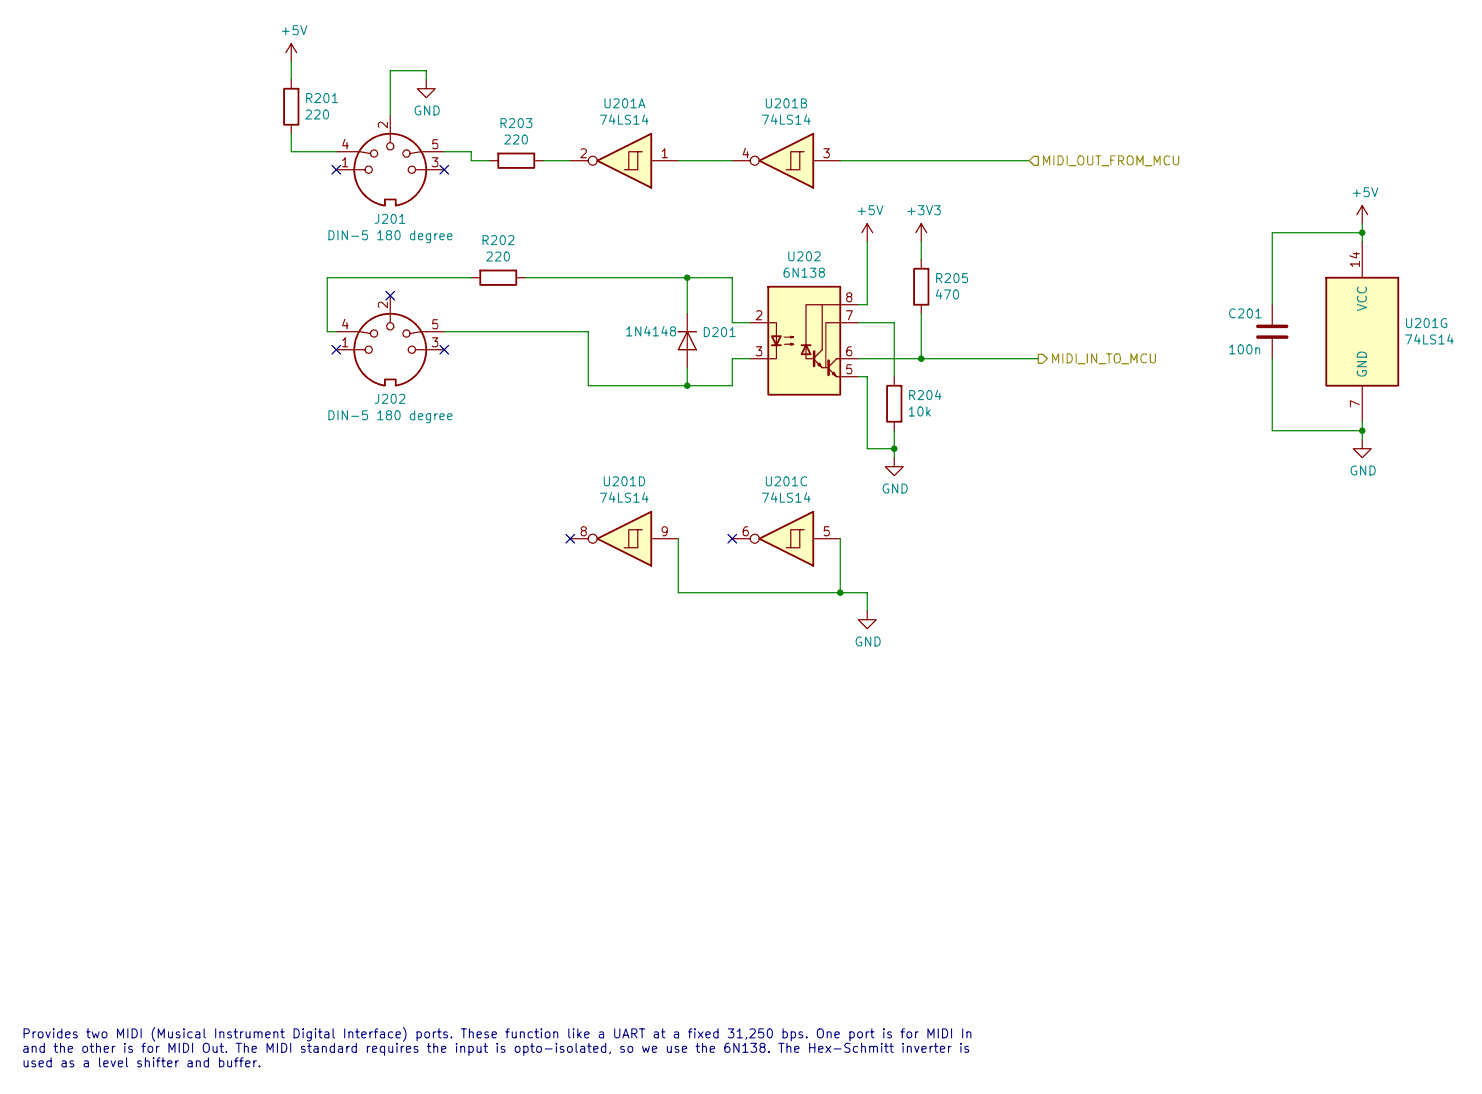
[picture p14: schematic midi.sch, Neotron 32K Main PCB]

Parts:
C201: 100n; C_Disc_D3.0mm_W2.0mm_P2.50mm; mpn K104K15X7RF5TL2
D201: 1N4148; D_DO-35_SOD27_P7.62mm_Horizontal; mpn 1N4148TR
J201, J202: DIN-5 180 degree; 5P180_DIN_Socket; mpn 491-087
R201, R202, R203: 220; R_Axial_DIN0207_L6.3mm_D2.5mm_P10.16mm_Horizontal; mpn CF14JT220R; digikey# CF14JT220RCT-ND
R204: 10k; R_Axial_DIN0207_L6.3mm_D2.5mm_P10.16mm_Horizontal; mpn CF14JT10K0; digikey# CF14JT10K0CT-ND
R205: 470; R_Axial_DIN0207_L6.3mm_D2.5mm_P10.16mm_Horizontal; mpn CF14JT470R; digikey# CF14JT470RCT-ND
U201: 74LS14; DIP-14_W7.62mm; mpn SN74LS14N;ED14DT
U202: 6N138; DIP-8_W7.62mm; mpn 6N138;ED08DT

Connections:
+5V: C201.1, R201.2, U201.14 (VCC), U202.8 (VCC); also elsewhere on the board
/PC6_MIDI_IN: R205.1, U202.6 (VO2); also elsewhere on the board
/PC7_MIDI_OUT: U201.3; also elsewhere on the board
GND: C201.2, J201.2, R204.1, U201.5, U201.7 (GND), U201.9, U202.5 (GND); also elsewhere on the board
unnamed: D201.1 (K), R202.1, U202.2 (C1)
unnamed: D201.2 (A), J202.5, U202.3 (C2)
unnamed: J201.4, R201.1
unnamed: J201.5, R203.2
unnamed: J202.4, R202.2
unnamed: R203.1, U201.2
unnamed: R204.2, U202.7 (VO1)
unnamed: U201.1, U201.4

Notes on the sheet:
Provides two MIDI (Musical Instrument Digital Interface) ports. These function like a UART at a fixed 31,250 bps. One port is for MIDI In and the other is for MIDI Out. The MIDI standard requires the input is opto-isolated, so we use the 6N138. The Hex-Schmitt inverter is used as a level shifter an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

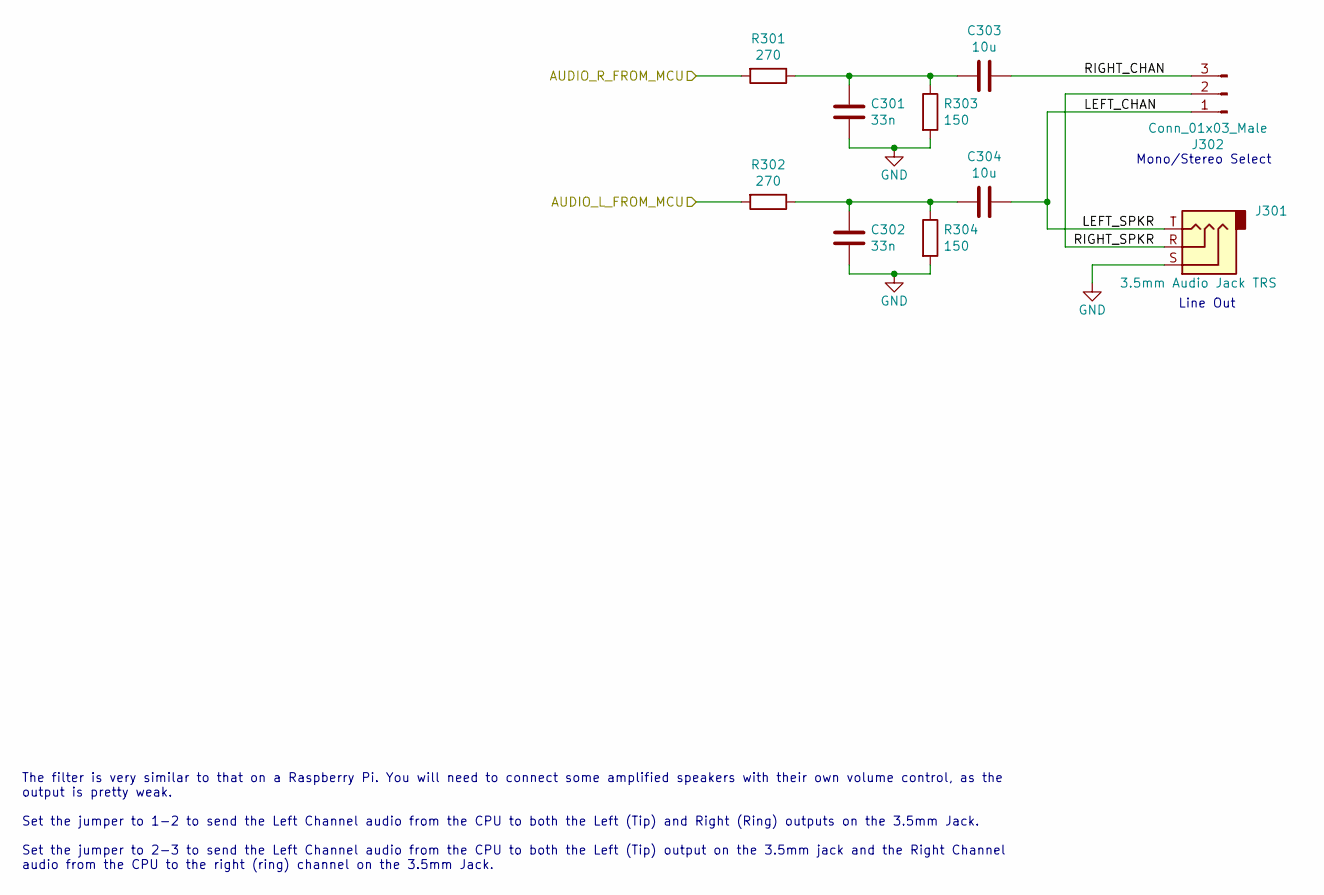
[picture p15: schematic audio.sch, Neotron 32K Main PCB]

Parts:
C301, C302: 33n; C_Disc_D3.0mm_W2.0mm_P2.50mm; mpn K333K15X7RF5TL2
C303, C304: 10u; CP_Radial_D6.3mm_P2.50mm; mpn MAL203858109E3
J301: 3.5mm Audio Jack TRS; Jack_3.5mm_CUI_SJ1-3533NG_Horizontal; mpn SJ1-3533NG
J302: Conn_01x03_Male; PinHeader_1x03_P2.54mm_Vertical
R301, R302: 270; R_Axial_DIN0207_L6.3mm_D2.5mm_P10.16mm_Horizontal; mpn CF14JT270R; digikey# CF14JT270RCT-ND
R303, R304: 150; R_Axial_DIN0207_L6.3mm_D2.5mm_P10.16mm_Horizontal; mpn CF14JT150R; digikey# CF14JT150RCT-ND

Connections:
/Audio/LEFT_CHAN: C304.2, J301.T, J302.1
/Audio/RIGHT_CHAN: C303.2, J302.3
/Audio/RIGHT_SPKR: J301.R, J302.2
/PE4_AUDIO_L: R302.2; also elsewhere on the board
/PE5_AUDIO_R: R301.2; also elsewhere on the board
GND: C301.1, C302.1, J301.S, R303.2, R304.2; also elsewhere on the board
unnamed: C301.2, C303.1, R301.1, R303.1
unnamed: C302.2, C304.1, R302.1, R304.1

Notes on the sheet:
Mono/Stereo Select
Line Out
The filter is very similar to that on a Raspberry Pi. You will need to connect some amplified speakers with their own volume control, as the output is pretty weak. Set the jumper to 1-2 to send the Left Channel audio from the CPU to both the Left (Tip) and Right (Ring) outputs on the 3.5mm Jack. Se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

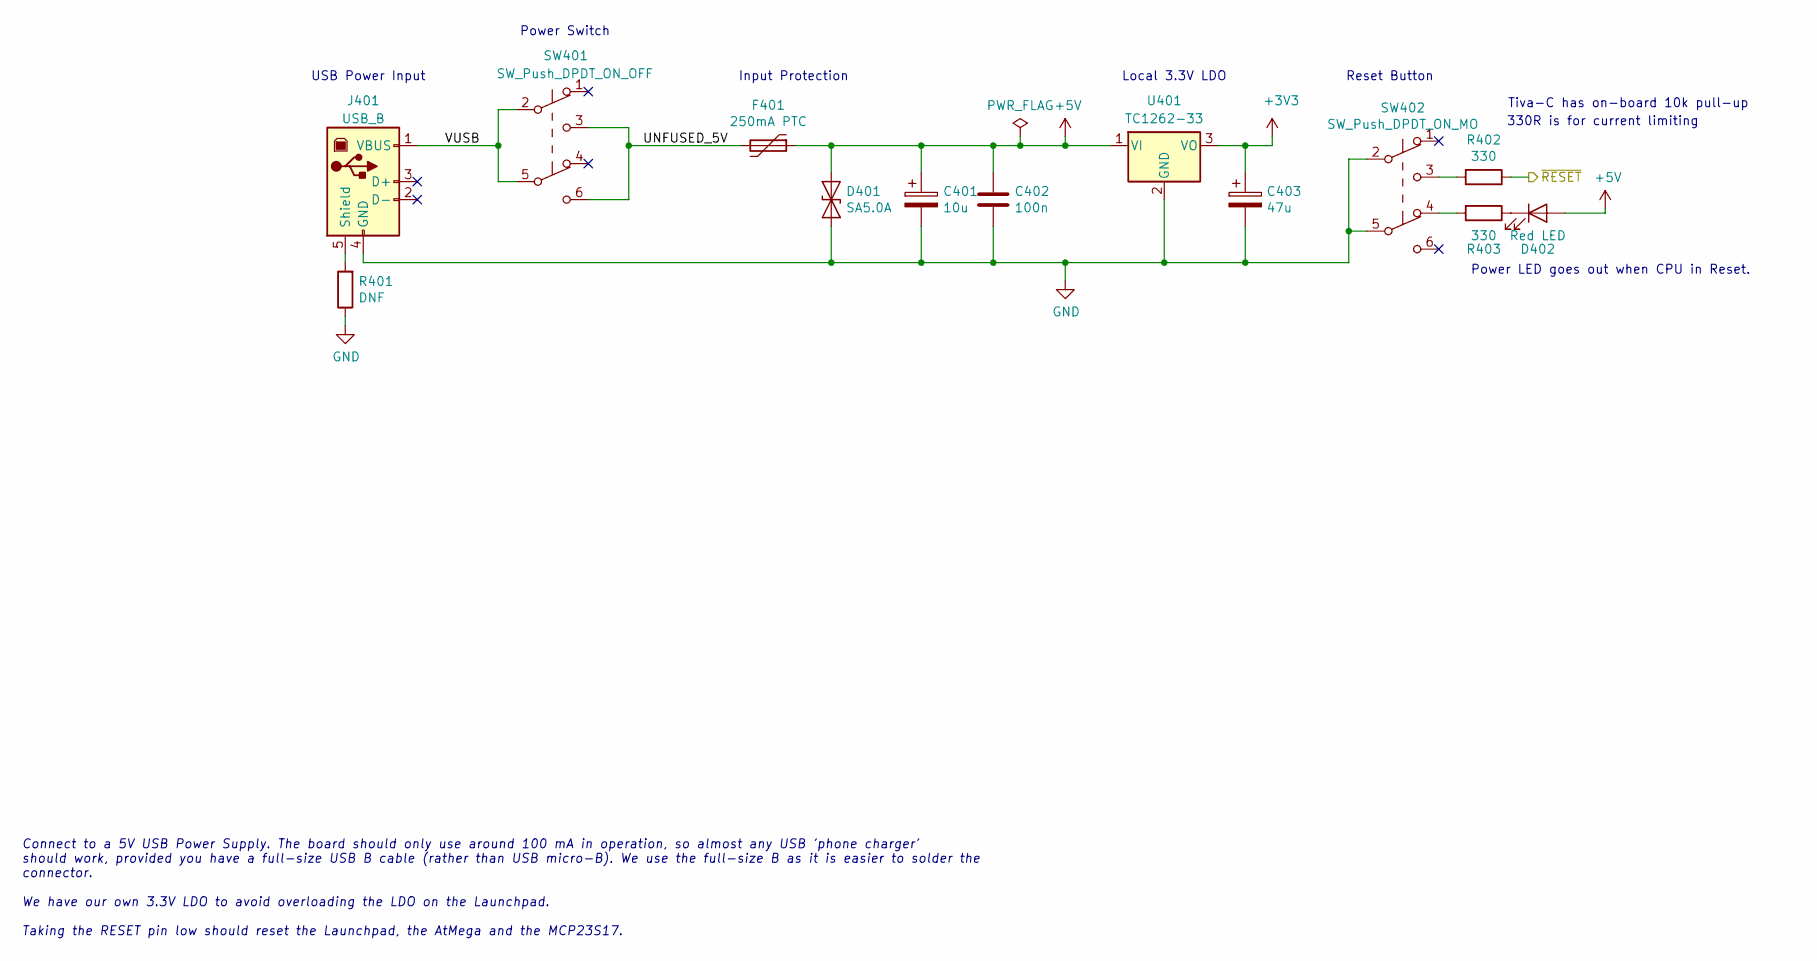
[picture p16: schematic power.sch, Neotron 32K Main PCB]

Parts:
C401: 10u; CP_Radial_D6.3mm_P2.50mm; mpn MAL203858109E3
C402: 100n; C_Disc_D3.0mm_W2.0mm_P2.50mm; mpn K104K15X7RF5TL2
C403: 47u; CP_Radial_D6.3mm_P2.50mm; mpn MAL214250479E3
D401: SA5.0A; D_DO-15_P12.70mm_Horizontal; mpn SA5.0A
D402: Red LED; LED_D3.0mm; mpn 151031SS04000
F401: 250mA PTC; Fuse_Littelfuse_395Series; mpn RXEF025
J401: USB_B; USB_B_OST_USB-B1HSxx_Horizontal; mpn USB-B1HSB6
R401: DNF; R_Axial_DIN0207_L6.3mm_D2.5mm_P10.16mm_Horizontal
R402, R403: 330; R_Axial_DIN0207_L6.3mm_D2.5mm_P10.16mm_Horizontal; mpn CF14JT330R; digikey# CF14JT330RCT-ND
SW401: SW_Push_DPDT_ON_OFF; PHB2UEETS1A; mpn PHB2UEETS1A
SW402: SW_Push_DPDT_ON_MO; PHB2UEETS1A; mpn PHB2UOATS1A
U401: TC1262-33; TO-220-3_Vertical; mpn TC1262-3.3VAB

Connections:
+5V: C401.1, C402.1, D401.1 (A1), D402.2 (A), F401.1, U401.1 (VI); also elsewhere on the board
/Power/UNFUSED_5V: F401.2, SW401.3 (C), SW401.6 (C)
/Power/VUSB: J401.1 (VBUS), SW401.2 (B), SW401.5 (B)
/~RESET: R402.1; also elsewhere on the board
GND: C401.2, C402.2, C403.2, D401.2 (A2), J401.4 (GND), R401.1, SW402.2 (B), SW402.5 (B), U401.2 (GND); also elsewhere on the board
unnamed: D402.1 (K), R403.1
unnamed: J401.5 (Shield), R401.2
unnamed: R402.2, SW402.3 (C)
unnamed: R403.2, SW402.4 (A)

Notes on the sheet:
Reset Button
Input Protection
Power Switch
USB Power Input
Local 3.3V LDO
Tiva-C has on-board 10k pull-up
330R is for current limiting
Connect to a 5V USB Power Supply. The board should only use around 100 mA in operation, so almost any USB 'phone charger' should work, provided you have a full-size USB B cable (rather than USB micro-B). We use the full-size B as it is easier to solder the connector. We have our own 3.3V LDO to avo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
Power LED goes out when CPU in Reset.

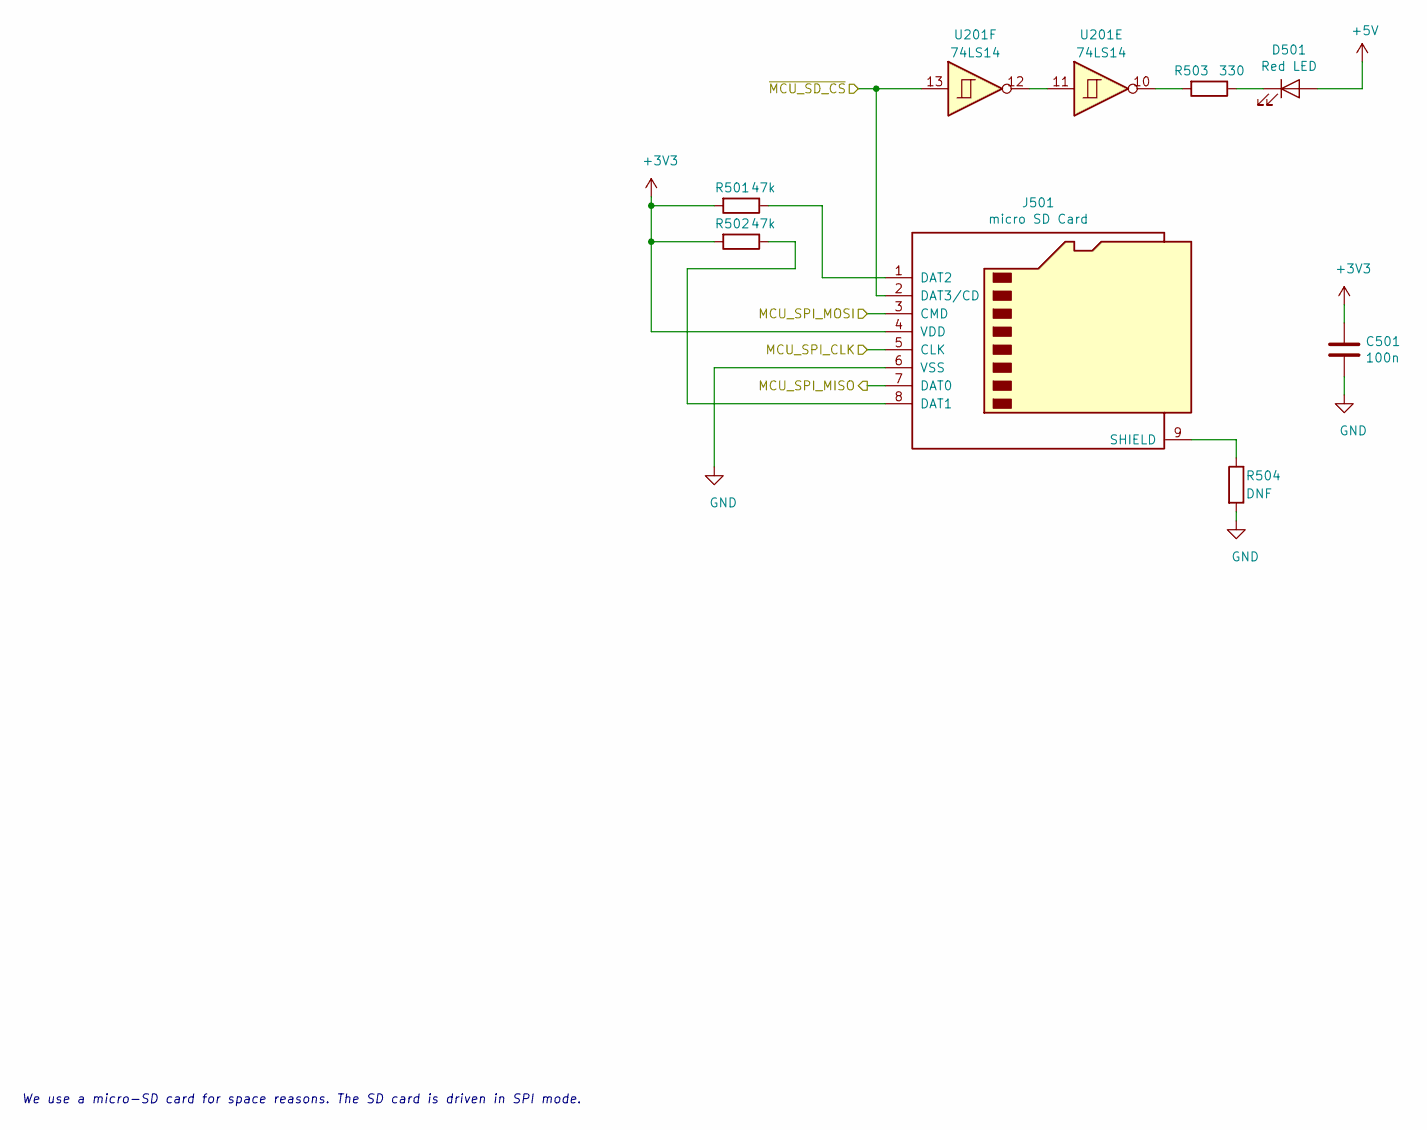
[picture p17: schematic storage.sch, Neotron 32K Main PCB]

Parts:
C501: 100n; C_Disc_D3.0mm_W2.0mm_P2.50mm; mpn K104K15X7RF5TL2
D501: Red LED; LED_D3.0mm; mpn 151031SS04000
J501: micro SD Card; Molex_4730_2651; mpn 47309-2651
R501, R502: 47k; R_Axial_DIN0207_L6.3mm_D2.5mm_P10.16mm_Horizontal; mpn CF14JT47K0; digikey# CF14JT47K0CT-ND
R503: 330; R_Axial_DIN0207_L6.3mm_D2.5mm_P10.16mm_Horizontal; mpn CF14JT330R; digikey# CF14JT330RCT-ND
R504: DNF; R_Axial_DIN0207_L6.3mm_D2.5mm_P10.16mm_Horizontal
U201: 74LS14; DIP-14_W7.62mm; mpn SN74LS14N;ED14DT

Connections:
+5V: D501.2 (A); also elsewhere on the board
/PA2_SPI_CLK: J501.5 (CLK); also elsewhere on the board
/PA4_SPI_MISO: J501.7 (DAT0); also elsewhere on the board
/PA5_SPI_MOSI: J501.3 (CMD); also elsewhere on the board
/~PA3_SPI_CS0: J501.2 (DAT3/CD), U201.13; also elsewhere on the board
GND: C501.2, J501.6 (VSS), R504.2; also elsewhere on the board
unnamed: D501.1 (K), R503.1
unnamed: J501.1 (DAT2), R501.1
unnamed: J501.8 (DAT1), R502.1
unnamed: J501.9 (SHIELD), R504.1
unnamed: R503.2, U201.10
unnamed: U201.11, U201.12

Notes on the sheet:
We use a micro-SD card for space reasons. The SD card is driven in SPI mode.

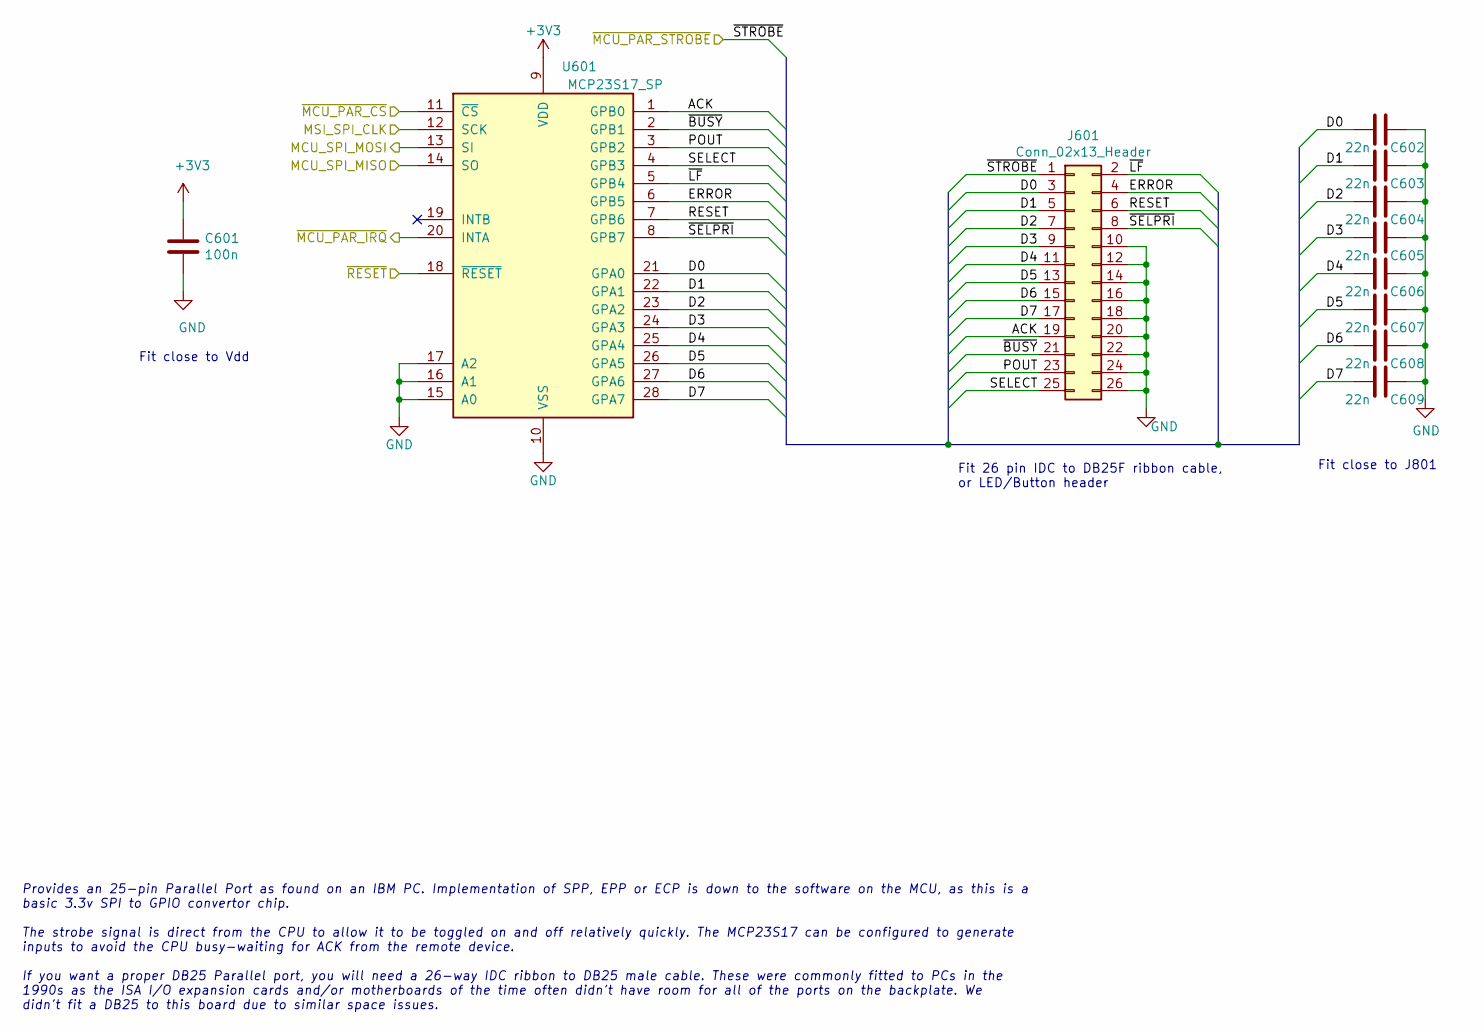
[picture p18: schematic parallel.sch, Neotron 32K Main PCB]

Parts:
C601: 100n; C_Disc_D3.0mm_W2.0mm_P2.50mm; mpn K104K15X7RF5TL2
C602, C603, C604, C605, C606, C607, C608, C609: 22n; C_Disc_D3.0mm_W2.0mm_P2.50mm; mpn K223K15X7RF5TL2
J601: Conn_02x13_Header; IDC-Header_2x13_P2.54mm_Vertical; mpn 302-S261
U601: MCP23S17_SP; DIP-28_W7.62mm; mpn MCP23S17-E/SP;ED281DT

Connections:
/PA2_SPI_CLK: U601.12 (SCK); also elsewhere on the board
/PA4_SPI_MISO: U601.14 (SO); also elsewhere on the board
/PA5_SPI_MOSI: U601.13 (SI); also elsewhere on the board
/Parallel Printer/ACK: J601.19, U601.1 (GPB0)
/Parallel Printer/D0: C602.2, J601.3, U601.21 (GPA0)
/Parallel Printer/D1: C603.2, J601.5, U601.22 (GPA1)
/Parallel Printer/D2: C604.2, J601.7, U601.23 (GPA2)
/Parallel Printer/D3: C605.2, J601.9, U601.24 (GPA3)
/Parallel Printer/D4: C606.2, J601.11, U601.25 (GPA4)
/Parallel Printer/D5: C607.2, J601.13, U601.26 (GPA5)
/Parallel Printer/D6: C608.2, J601.15, U601.27 (GPA6)
/Parallel Printer/D7: C609.2, J601.17, U601.28 (GPA7)
/Parallel Printer/ERROR: J601.4, U601.6 (GPB5)
/Parallel Printer/POUT: J601.23, U601.3 (GPB2)
/Parallel Printer/RESET: J601.6, U601.7 (GPB6)
/Parallel Printer/SELECT: J601.25, U601.4 (GPB3)
/Parallel Printer/~BUSY: J601.21, U601.2 (GPB1)
/Parallel Printer/~LF: J601.2, U601.5 (GPB4)
/Parallel Printer/~SELPRI: J601.8, U601.8 (GPB7)
/~PB2_STROBE: J601.1; also elsewhere on the board
/~PB3_SPI_CS1: U601.11 (~CS~); also elsewhere on the board
/~PF0_IRQ1: U601.20 (INTA); also elsewhere on the board
/~RESET: U601.18 (~RESET~); also elsewhere on the board
GND: C601.2, C602.1, C603.1, C604.1, C605.1, C606.1, C607.1, C608.1, C609.1, J601.10, J601.12, J601.14, J601.16, J601.18, J601.20, J601.22, J601.24, J601.26, U601.10 (VSS), U601.15 (A0), U601.16 (A1), U601.17 (A2); also elsewhere on the board

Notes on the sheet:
Fit 26 pin IDC to DB25F ribbon cable, or LED/Button header
Fit close to J801
Fit close to Vdd
Provides an 25-pin Parallel Port as found on an IBM PC. Implementation of SPP, EPP or ECP is down to the software on the MCU, as this is a basic 3.3v SPI to GPIO convertor chip. The strobe signal is direct from the CPU to allow it to be toggled on and off relatively quickly. The MCP23S17 can be con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

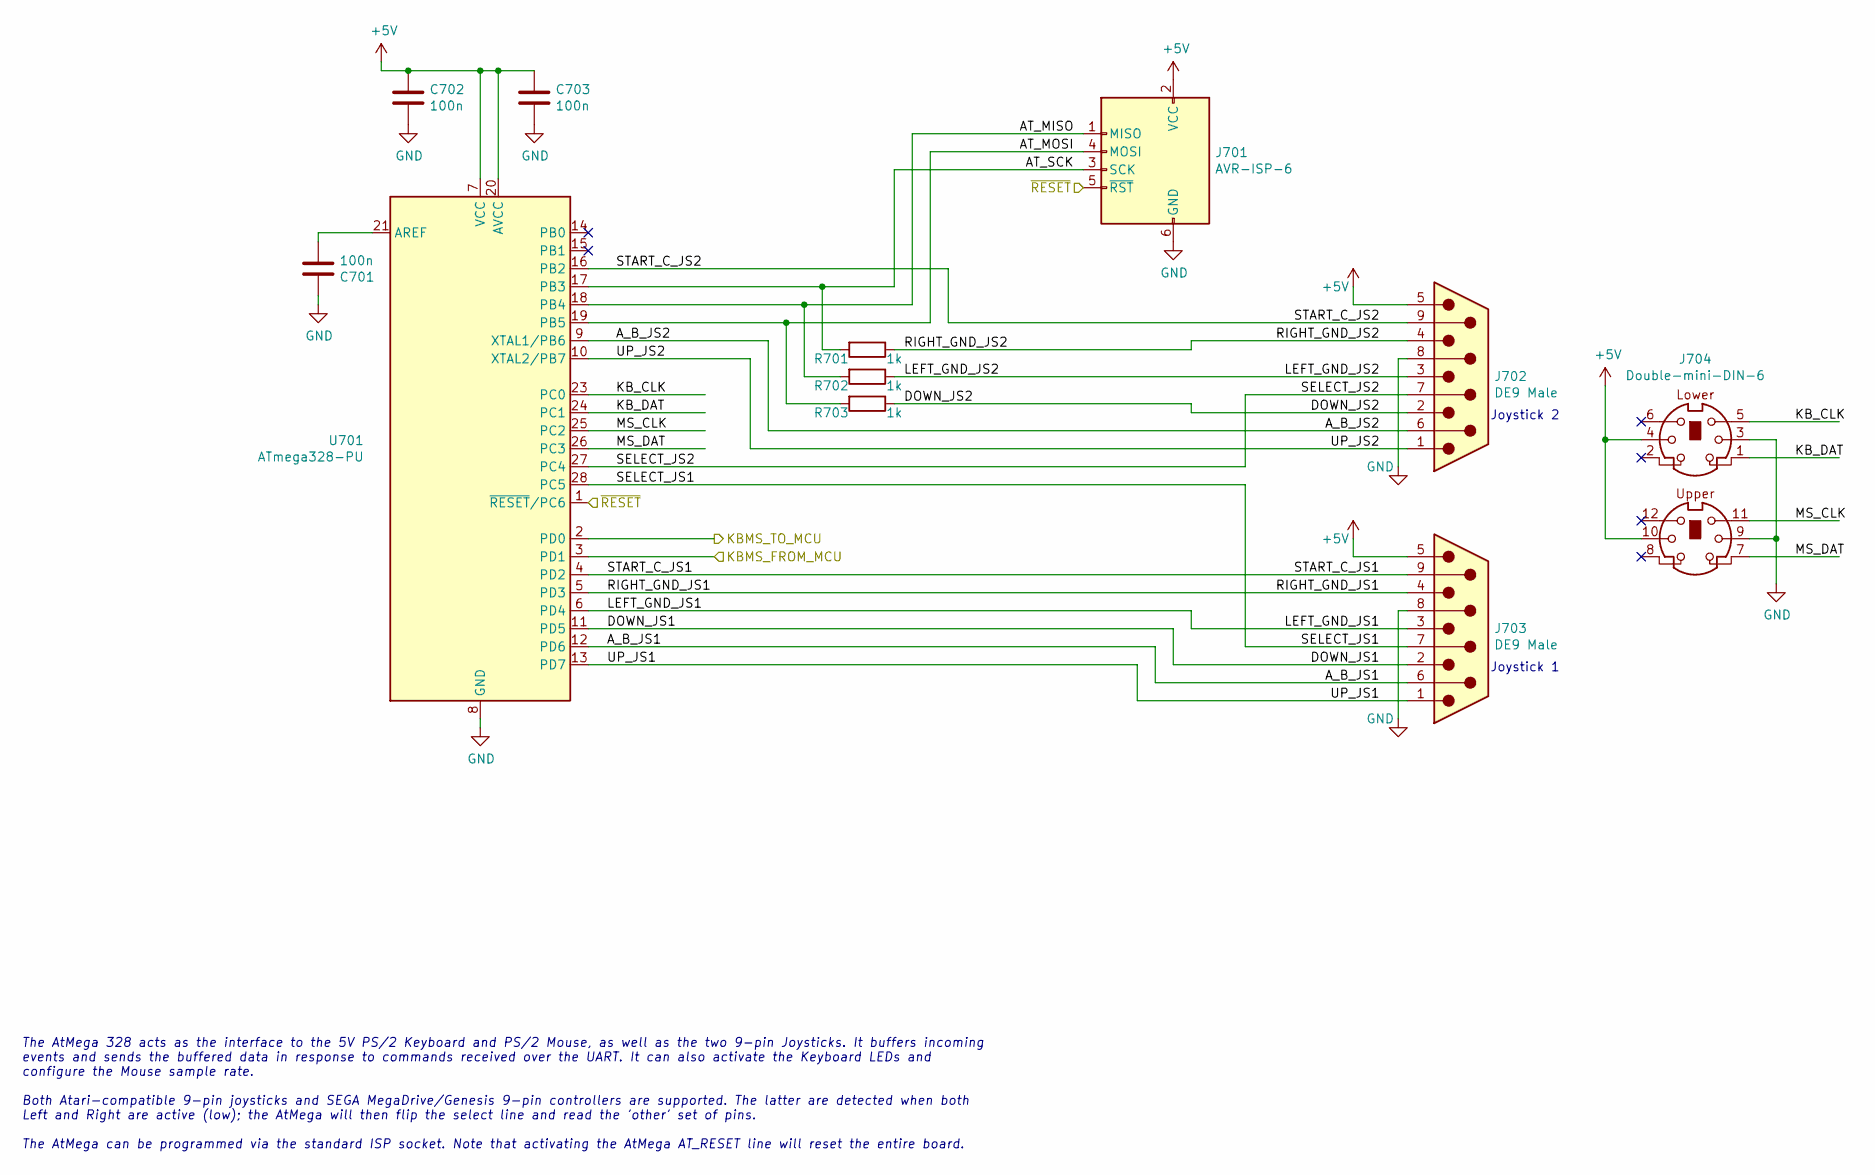
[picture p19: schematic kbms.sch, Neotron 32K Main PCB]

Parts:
C701, C702, C703: 100n; C_Disc_D3.0mm_W2.0mm_P2.50mm; mpn K104K15X7RF5TL2
J701: AVR-ISP-6; PinHeader_2x03_P2.54mm_Vertical; mpn M20-9760346
J702, J703: DE9 Male; DSUB-9_Male_Horizontal_P2.77x2.84mm_EdgePinOffset14.56mm_Ho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; mpn 5747467-2
J704: Double-mini-DIN-6; Double_mini-DIN_6; mpn KMDGX-6S-6S-S4N.
R701, R702, R703: 1k; R_Axial_DIN0207_L6.3mm_D2.5mm_P10.16mm_Horizontal; mpn CF14JT1K00; digikey# CF14JT1K00CT-ND
U701: ATmega328-PU; DIP-28_W7.62mm; mpn ATmega328-PU;ED281DT

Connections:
+5V: C702.1, C703.1, J701.2 (VCC), J702.5, J703.5, J704.4, J704.10, U701.7 (VCC), U701.20 (AVCC); also elsewhere on the board
/Keyboard, Mouse and Joystick/AT_MISO: J701.1 (MISO), R702.2, U701.18 (PB4)
/Keyboard, Mouse and Joystick/AT_MOSI: J701.4 (MOSI), R703.2, U701.19 (PB5)
/Keyboard, Mouse and Joystick/AT_SCK: J701.3 (SCK), R701.2, U701.17 (PB3)
/Keyboard, Mouse and Joystick/A_B_JS1: J703.6, U701.12 (PD6)
/Keyboard, Mouse and Joystick/A_B_JS2: J702.6, U701.9 (XTAL1/PB6)
/Keyboard, Mouse and Joystick/DOWN_JS1: J703.2, U701.11 (PD5)
/Keyboard, Mouse and Joystick/DOWN_JS2: J702.2, R703.1
/Keyboard, Mouse and Joystick/KB_CLK: J704.5, U701.23 (PC0)
/Keyboard, Mouse and Joystick/KB_DAT: J704.1, U701.24 (PC1)
/Keyboard, Mouse and Joystick/LEFT_GND_JS1: J703.3, U701.6 (PD4)
/Keyboard, Mouse and Joystick/LEFT_GND_JS2: J702.3, R702.1
/Keyboard, Mouse and Joystick/MS_CLK: J704.11, U701.25 (PC2)
/Keyboard, Mouse and Joystick/MS_DAT: J704.7, U701.26 (PC3)
/Keyboard, Mouse and Joystick/RIGHT_GND_JS1: J703.4, U701.5 (PD3)
/Keyboard, Mouse and Joystick/RIGHT_GND_JS2: J702.4, R701.1
/Keyboard, Mouse and Joystick/SELECT_JS1: J703.7, U701.28 (PC5)
/Keyboard, Mouse and Joystick/SELECT_JS2: J702.7, U701.27 (PC4)
/Keyboard, Mouse and Joystick/START_C_JS1: J703.9, U701.4 (PD2)
/Keyboard, Mouse and Joystick/START_C_JS2: J702.9, U701.16 (PB2)
/Keyboard, Mouse and Joystick/UP_JS1: J703.1, U701.13 (PD7)
/Keyboard, Mouse and Joystick/UP_JS2: J702.1, U701.10 (XTAL2/PB7)
/PE0_U7RX: U701.2 (PD0); also elsewhere on the board
/PE1_U7TX: U701.3 (PD1); also elsewhere on the board
/~PF4_AT_RESET: J701.5 (~RST), U701.1 (~RESET~/PC6); also elsewhere on the board
GND: C701.1, C702.2, C703.2, J701.6 (GND), J702.8, J703.8, J704.3, J704.9, U701.8 (GND), U701.22 (GND); also elsewhere on the board
unnamed: C701.2, U701.21 (AREF)

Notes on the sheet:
Joystick 1
Joystick 2
The AtMega 328 acts as the interface to the 5V PS/2 Keyboard and PS/2 Mouse, as well as the two 9-pin Joysticks. It buffers incoming events and sends the buffered data in response to commands received over the UART. It can also activate the Keyboard LEDs and configure the Mouse sample rate. Both At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

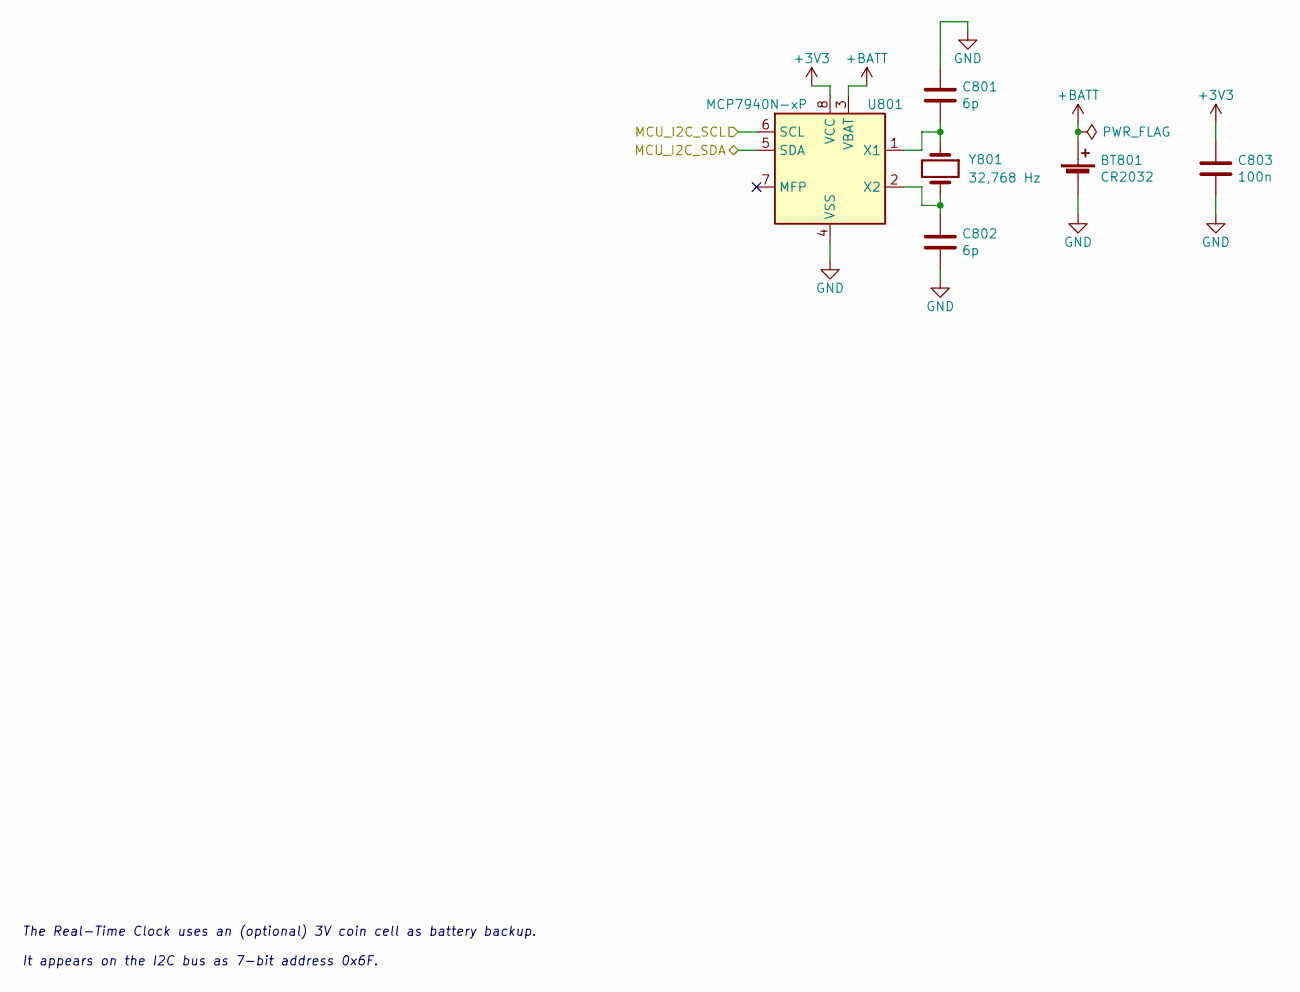
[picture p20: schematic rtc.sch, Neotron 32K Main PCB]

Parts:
BT801: CR2032; BatteryHolder_Keystone_103_1x20mm; mpn 103;CR2032
C801, C802: 6p; C_Disc_D3.0mm_W2.0mm_P2.50mm; mpn FG18C0G1H060DNT06
C803: 100n; C_Disc_D3.0mm_W2.0mm_P2.50mm; mpn K104K15X7RF5TL2
U801: MCP7940N-xP; DIP-8_W7.62mm; mpn MCP7940N-I/P;ED08DT
Y801: 32,768 Hz; Crystal_C26-LF_D2.1mm_L6.5mm_Horizontal; mpn CFS-20632768DZBB

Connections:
+BATT: BT801.1 (+), U801.3 (VBAT)
/PA6_I2C_SCL: U801.6 (SCL); also elsewhere on the board
/PA7_I2C_SDA: U801.5 (SDA); also elsewhere on the board
GND: BT801.2 (-), C801.1, C802.2, C803.2, U801.4 (VSS); also elsewhere on the board
unnamed: C801.2, U801.1 (X1), Y801.1
unnamed: C802.1, U801.2 (X2), Y801.2

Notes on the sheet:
The Real-Time Clock uses an (optional) 3V coin cell as battery backup. It appears on the I2C bus as 7-bit address 0x6F.

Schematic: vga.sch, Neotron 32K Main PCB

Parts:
J901: DB15HD_Female; DSUB-15-HD_Female_Horizontal_P2.29x1.98mm_EdgePinOffset3.03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; mpn ICD15S13E4GV00LF
R901, R902, R903: 330; R_Axial_DIN0207_L6.3mm_D2.5mm_P10.16mm_Horizontal; mpn CF14JT330R; digikey# CF14JT330RCT-ND
R904: DNF; R_Axial_DIN0207_L6.3mm_D2.5mm_P10.16mm_Horizontal
R905, R906: 330; R_Axial_DIN0207_L6.3mm_D2.5mm_P10.16mm_Horizontal; mpn CF14JT470R; digikey# CF14JT470RCT-ND

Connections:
/PB4_VGA_HSYNC: R905.1; also elsewhere on the board
/PB5_VGA_VSYNC: R906.1; also elsewhere on the board
/PB7_VGA_GREEN: R902.2; also elsewhere on the board
/PD3_VGA_BLUE: R903.2; also elsewhere on the board
/PF1_VGA_RED: R901.2; also elsewhere on the board
GND: J901.5, J901.6, J901.7, J901.8, R904.1; also elsewhere on the board
unnamed: J901.0, R904.2
unnamed: J901.1, R901.1
unnamed: J901.2, R902.1
unnamed: J901.3, R903.1
unnamed: J901.13, R905.2
unnamed: J901.14, R906.2

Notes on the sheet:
The VGA output is driven directly from the GPIO pins using a resistive divider. The output impedance is therefore all wrong. Best results are with an LCD monitor and a short VGA cable. We've also had success using a cheap VGA to HDMI adaptor connected directly to the VGA output port. In case of iss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

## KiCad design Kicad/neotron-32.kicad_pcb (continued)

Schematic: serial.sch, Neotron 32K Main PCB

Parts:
C1001, C1002: 100n; C_Disc_D3.0mm_W2.0mm_P2.50mm; mpn K104K15X7RF5TL2
C1003, C1004, C1005: 100n; C_Disc_D3.0mm_W2.0mm_P2.50mm; mpn K474Z20Y5VE5TL2
J1001: Conn_02x05; IDC-Header_2x05_P2.54mm_Vertical; mpn 302-S101
U1001: ICL3232CPZMAX; DIP-16_W7.62mm; mpn ICL3232CPZ;ED16DT

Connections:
/PB0_U1RX: U1001.12 (R1OUT); also elsewhere on the board
/PB1_U1TX: U1001.11 (T1IN); also elsewhere on the board
/PC4_U1RTS: U1001.10 (T2IN); also elsewhere on the board
/PC5_U1CTS: U1001.9 (R2OUT); also elsewhere on the board
/RS-232 Serial Port/RS232_CTS_IN: J1001.8, U1001.8 (R2IN)
/RS-232 Serial Port/RS232_RTS_OUT: J1001.7, U1001.7 (T2OUT)
/RS-232 Serial Port/RS232_RX_IN: J1001.2, U1001.13 (R1IN)
/RS-232 Serial Port/RS232_TX_OUT: J1001.3, U1001.14 (T1OUT)
GND: C1001.1, C1004.1, J1001.5, U1001.15 (GND); also elsewhere on the board
unnamed: C1002.1, U1001.3 (C1-)
unnamed: C1002.2, U1001.1 (C1+)
unnamed: C1003.1, U1001.4 (C2+)
unnamed: C1003.2, U1001.5 (C2-)
unnamed: C1004.2, U1001.6 (VS-)
unnamed: C1005.2, U1001.2 (VS+)

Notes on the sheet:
Header for IDC to DE9 Ribbon. Wired DTE.
This chip is a 3.3V capable version of the MAX232 RS-232 level shifter. The port is wired DTE (i.e. as if this was an IBM PC, rather than as a modem). We only have a five-wire RS-232 interface, missing the Ring Input, Data Set Ready, Data Terminal Ready and Carrier Detect pins. If you want a proper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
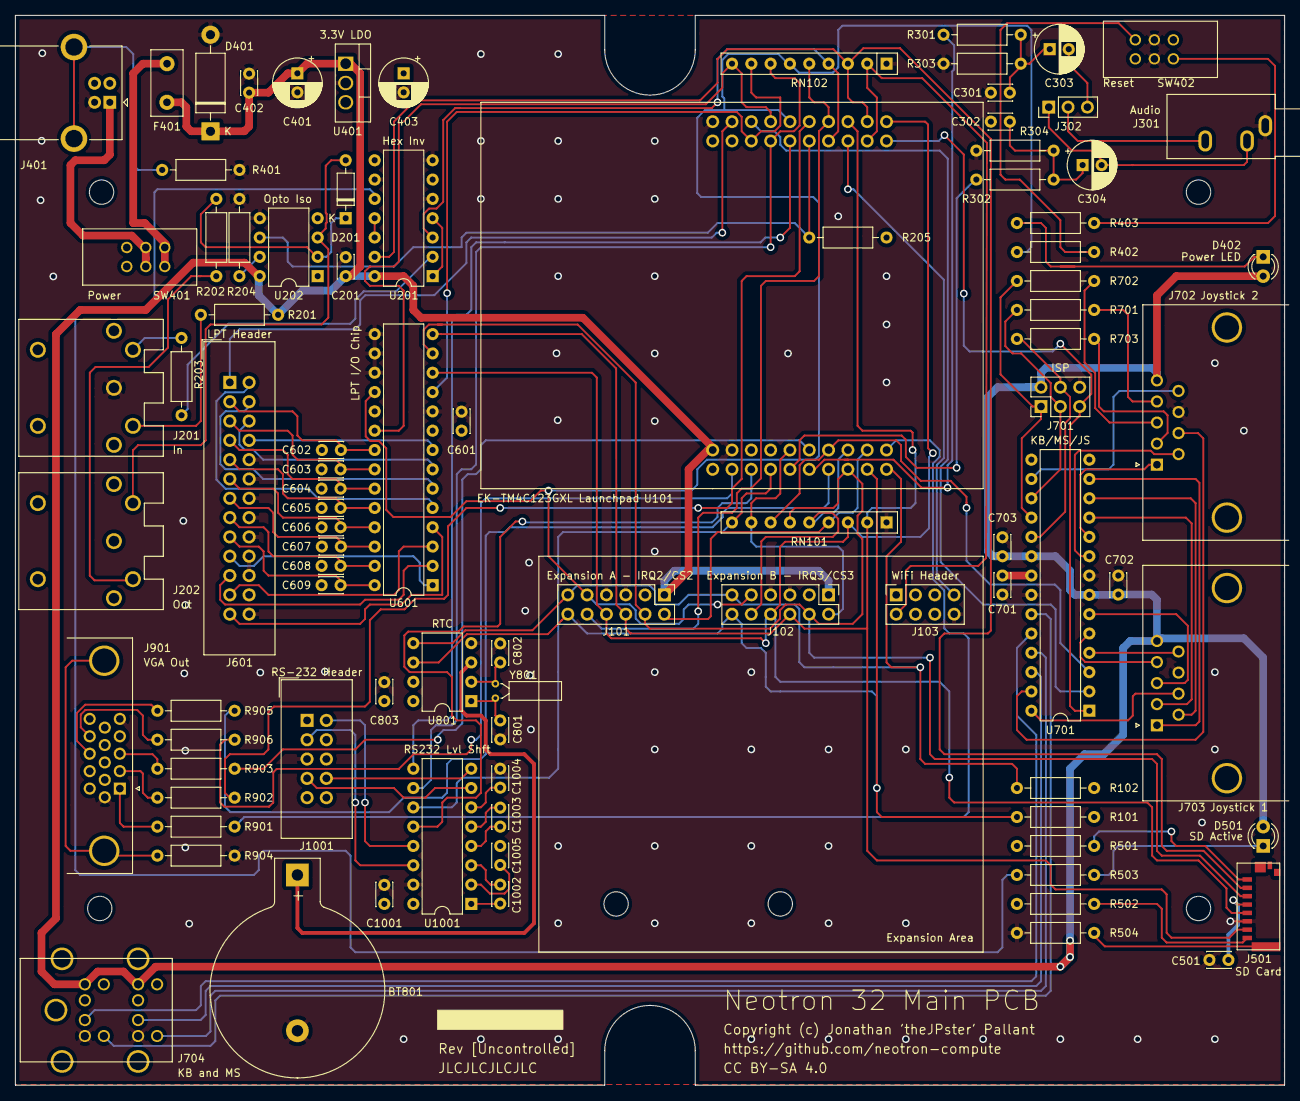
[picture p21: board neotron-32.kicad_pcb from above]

Board: 4 copper layers, 166.9 x 140.7 mm, 97 parts (0 on the bottom side), 117 nets.

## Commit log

2019-11-10 Skeleton schematic.
    [neotron-32.kicad_pcb, neotron-32.sch]
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2019-12-09 Adding sub-sheets
    [audio.sch, joysticks.sch, kbms.sch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]
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2019-12-09 Added some footprints. Basic board outline.
    [audio.sch, joysticks.sch, kbms.sch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]
2019-12-10 Completed Power, SD, MIDI, Parallel and Joystick sheets.
    Switch to sheet based 100x part numbering.
    [audio.sch, joysticks.sch, kbms.sch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]
2019-12-15 Schematic capture draft complete.
    [audio.sch, joysticks.sch, kbms.sch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]
2019-12-16 Tidied up Atmega power. Added page titles.
    [audio.sch, kbms.sch, midi.sch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]
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2019-12-19 Updated footprints: ) Swapped RS-232 DE9 for IDC header. ) Large caps are radial electrolytics. ) Made resistors a little smaller.
    [audio.sch, kbms.sch, midi.sch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]
2019-12-19 Laid out components. Tracking partially complete.
    [neotron-32.kicad_pcb]
2019-12-19 First draft layout complete. Fixing DRC issues.
    [neotron-32.kicad_pcb, neotron-32.sch]
2019-12-19 Layout first draft complete - passes DRC.
    Still need to nudge a few traces on to the grid.
    Also need to move all the silkscreen labels into place.
    [neotron-32.kicad_pcb]
2019-12-19 Tidied some more tracks.
    [neotron-32.kicad_pcb]
2019-12-20 Finished layout and silkscreen.
    [audio.sch, kbms.sch, midi.sch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]
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2019-12-21 Set version to [Uncontrolled].
    Replace [Uncontrolled] with actual revision in each release branch.
    [audio.sch, joysticks.sch, kbms.sch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]
2019-12-21 Replace two PS/2 headers with single double-header.
    [kbms.sch, neotron-32.kicad_pcb]
2019-12-21 Replaced keyboard/mouse connect with double PS/2 header.
    Jiggled around PCB layout to line more tracks up on grid.
    [kbms.sch, neotron-32.kicad_pcb]
2019-12-21 Replaced broken Keystone 103 footprint with edited one.
    Stops annoying DRC error.
    [rtc.sch]
2019-12-21 Resolve last two DRC errors: ) use updated battery holder ) fix clearance on SD card
    [neotron-32.kicad_pcb]
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2019-12-23 Nudge sockets around, and switch to LibreCAD for end panels.
    End panel needs more work.
    [endpanels.dxf, neotron-32.kicad_pcb]
2019-12-23 Fix MIDI Out/Through mix-up.
    [midi.sch]
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2019-12-24 Re-laid out Joystick, MIDI and VGA.
    Re-worked Joystick connectors (were changed from Female to Male).
    Deleted MIDI Through.
    Moved up VGA connector.
    [neotron-32.kicad_pcb]
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2019-12-25 Use offset DE9 for Joysticks.
    [kbms.sch]
2019-12-25 Updated schematic on Windows.
    [audio.sch, midi.sch, neotron-32.sch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]
2019-12-25 Updated PCB layout:
    ) Moved Joystick ports inwards.
    ) Moved USB power connector inwards.
    ) Added copper pour on top layer.
    [neotron-32.kicad_pcb]
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2019-12-25 Removed Digikey and RS part numbers.
    [midi.sch, power.sch, rtc.sch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]
2019-12-26 Refill zones on Linux Kicad to avoid issues running release script.
    [neotron-32.kicad_pcb]
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2019-12-26 Add some extra explanatory notes.
    [audio.sch, kbms.sch, midi.sch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]
2019-12-27 Fixed up end panel to match current PCB.
    [endpanels.dxf]
2019-12-27 Fix Stackpole 1K part number.
    [kbms.sch, neotron-32.sch]
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2019-12-27 Add metadata to silkscreen.
    [neotron-32.kicad_pcb]
2019-12-27 Ensure all layers go into Gerber file as some were missing.
2019-12-27 Add USB 3D model - using compatible TE part.
    [c-292304-1-b-3d.stp, neotron-32.kicad_pcb]
2019-12-27 Add PS/2 connector model.
    [KMDGX-6S-6S-S4N_rB8.STEP, neotron-32.kicad_pcb]
2019-12-28 Add some more 3D models. Also add a 3D render to the README.
    [129c20533c2cd7dda318afc41ae7ab4f8828891e.step, c-5747467-2-b-3d.stp, neotron-32.kicad_pcb]
2019-12-28 PCB Updates.
    ) Moved SD LED next to SD card (makes space for future USB port)
    ) Set up Net Class for power tracks
    ) Set all power tracks to 0.5mm (suitable for up to 1A) - 1mm tracks were overkill
    [neotron-32.kicad_pcb]
2019-12-29 Rotate drive activity LED. Tidy up bottom layer traces.
    [neotron-32.kicad_pcb]
2020-01-03 Replace Amphenol SD connector with Molex.
    The Molex connector has the pins at the rear, which means you can blob
    down solder without fouling the card insertion.
    [473092651.stp, neotron-32.kicad_pcb, storage.sch]
2020-01-03 Move VGA connector in to align with PCB edge.
    [neotron-32.kicad_pcb]
2020-01-03 Remove yet another hole in the flood fill, near the Exp connectors.
    [neotron-32.kicad_pcb]
2020-01-04 Moved non-standard components into local libraries.
    neotron-32.lib is the symbol library.
    neotron-32.pretty is the footprint library.
    Also swapped the DE9 and DB25 headers for IDC boxed versions. Involved
    moving a resistor out of the way.
    The Keystone 103 battery holder is a straight copy of the standard
    footprint, but with the Courtyard removed to bypass the 'Courtyard is
    not closed' DRC error.
    [kbms.sch, midi.sch, neotron-32.kicad_pcb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]
2020-01-04 Add a push button power switch.
    Also moved reset into the corner and tidied up a few tracks.
    [neotron-32.kicad_pcb, power.sch]
2020-01-04 Fixed spacing between MIDI connectors.
    Also tidied up some more tracks and re-aligned end panel.
    [endpanels.dxf, neotron-32.kicad_pcb]
2020-01-05 Added Reset switch.
    Also added 3D models.
    [PHB2UOATS1ANS.stp, neotron-32.kicad_pcb, power.sch]
2020-01-05 Restore endpanel drawing.
    Not sure how the drawing was lost, but hurrah for git!
    [endpanels.dxf]
2020-01-05 Set output format to Gebers and PDF.
    [neotron-32.kicad_pcb]
2020-01-06 Moved some tracks away from the Neotron silkscreen text.
    Also removed some weird trace overlaps near the Wifi connector.
    [neotron-32.kicad_pcb]
2020-01-06 Laying out board again, but on a 50 mil grid for parts.
    Will use 25 mil grid for traces. This will hopefully avoid the issue
    of traces 'sticking' to legs rather than cleanly going precisely down
    the middle. It also looks a lot nicer now everything is properly
    aligned.
    I've also taken the opportunity to put the expansion slots all next to each other.
    Might need to add some support holes for some legs, a la M.2 SSDs.
    [neotron-32-old.kicad_pcb, neotron-32.kicad_pcb, power.sch]
2020-01-09 Added some more tracks.
    [neotron-32.kicad_pcb]
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2020-01-15 WIP on 4 layer.
    It's much easier than the two layer board!
    [neotron-32.kicad_pcb]
2020-01-16 Completed tracking. Just needs a tidy.
    [neotron-32.kicad_pcb]
2020-01-16 Tidied up layout a bit. Also ensured all four layers in release.sh.
    [neotron-32.kicad_pcb]
2020-01-16 Join VGA GND together.
    [neotron-32.kicad_pcb]
2020-01-17 Manhattan, not diagonals.
    Aligning tracks on north/south and east/west is more
    visually pleasing than taking the diagonal. Having to fight the autorouter
    a bit though. In an ideal work we'd have north/south on one layer
    and east/west on the other, but meh.
    [neotron-32.kicad_pcb]
2020-01-18 Swapped Wifi pin header for socket.
    [neotron-32.sch]
2020-01-18 Swapped WiFi pin header for socket. Removed 5V from 3.3V plane.
    [neotron-32.kicad_pcb]
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2020-01-19 Fixed footprints.
    ) Parallel port was wrongly numbered.
    ) Input fuse has 0.2" leg spacing.
    ) Also cleaned up a few more diagonals.
    [neotron-32.kicad_pcb, parallel.sch, power.sch]
2020-01-19 Last of the diagonals abolished.
    [neotron-32.kicad_pcb]
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2020-01-19 Updated endpanel using photo.
    [endpanels.dxf]
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2020-03-29 Bug fixes part 1.
    * Added XTAL to Atmega.
    * Added UART header to Atmega.
    * Added page numbers.
    * Removed the 470R in favour of 330R (to rationalise the BOM)
    * Replaced MAX3232 caps with 100n
    [kbms.sch, midi.sch, neotron-32.sch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]
2020-05-31 Replace PartNum with MPN so Kicost can see it.
    [audio.sch, kbms.sch, midi.sch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]
2020-05-31 Tweaks to the BOM.
    Marking parts as DNP=1 should stop them appearing in the BOM.
    Also set multi-parts for ICs in sockets.
    [audio.sch, kbms.sch, midi.sch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]
2020-06-01 Add some Digikey part numbers.
    [audio.sch, kbms.sch, midi.sch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]
2020-06-01 Add BOM for kitspace
    [kitspace-bom.csv]
2020-06-02 Cleaned up Atmega reset. Set hold size to 3.5mm, so M3 screws go through nicely Reset numbering to page x 100 Renamed Launchpad to EK-TM4C123GXL Renamed top-level signals to KBMS page as KBMS_TO/FROM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
    [audio.sch, kbms.sch, midi.sch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]
2020-06-02 Shift power and reset inwards. Add ground fill top/bottom.
    [neotron-32.kicad_pcb, storage.sch]
2020-06-04 Update BOM from Kicad.
    Exported with bom2grouped_csv.
    [kitspace-bom.csv]
2020-06-04 Rebuild BOM with new part numbers.
    [kitspace-bom.csv]
2020-06-04 Add link to Kitspace and new Octopart BOM.
    [kitspace-bom.csv]
2020-06-04 Fix #21 and #25.
    [neotron-32.kicad_pcb]
2020-06-12 Moving Kicad stuff into Kicad sub-folder.
    [audio.sch, kbms.sch, midi.sch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]
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2020-06-13 Deleted DNP parts, and added Digikey part numbers.
    [kitspace-bom.csv]
2020-06-13 Clean up BOM - add friendlier part descriptions.
    [kitspace-bom.csv]
2020-06-13 Change Harwin 12-pin header part number.
    [kitspace-bom.csv]
2020-09-05 Fixed up path to 3D models.
    Also tidied up a few tracks to get better top pour.
    [neotron-32.kicad_pcb]
